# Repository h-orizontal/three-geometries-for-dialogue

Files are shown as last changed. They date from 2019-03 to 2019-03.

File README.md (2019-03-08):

# Three geometries for dialogue
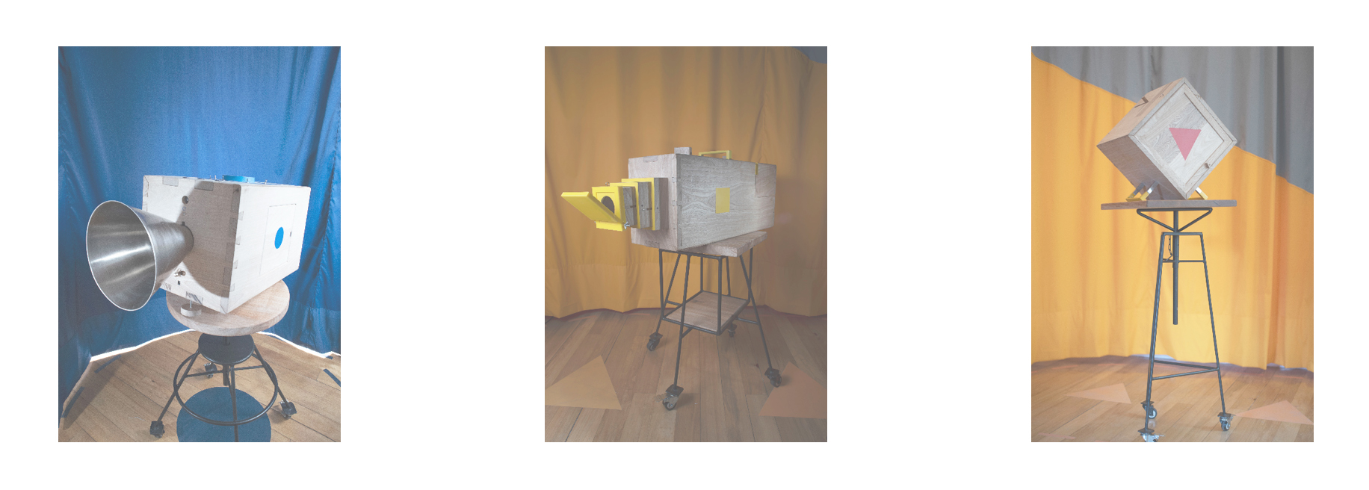
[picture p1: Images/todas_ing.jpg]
cajitas


These are three pedagogical tools that work as a support for psychosocial processes and exercises, as well as mediators in the participatory construction of a restorative justice space. These devices want to be translators of the life testimonies, feelings and circumstances that made the conflict or felony happen and transform them into communication exercises that bring facts closer and make them tangible, that foster dialogue and a mutual understanding of agreements and reparation.

Developed by [h-orizontal](http://h-orizontal.org/) alongside a group of collaborators, these devices are organized around three different communication systems: trace, sound and projection. Witch each box, [a series of workshops and a space intervention](http://h-orizontal.org/en/estrategia/restorative-justice-program-in-bogota/) were developed for the adolescents and professionals from the restorative justice program for adolescents in Bogotá, Colombia.

horizontal open sourced the design so that in the future they could be made by the adolescents themselves, other restorative justice initiatives or anyone interested in participative and interactive design processes.

To find out more, visit the [project website](http://h-orizontal.org/en/estrategia/pedagogic-tools-for-restorative-justice/).

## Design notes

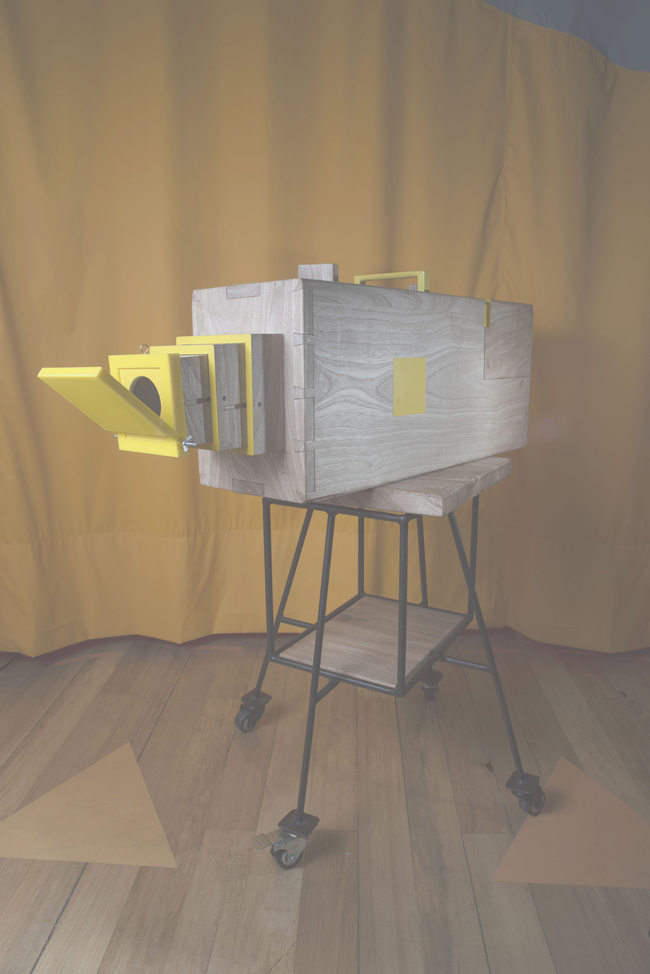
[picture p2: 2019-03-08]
Images/video.jpg

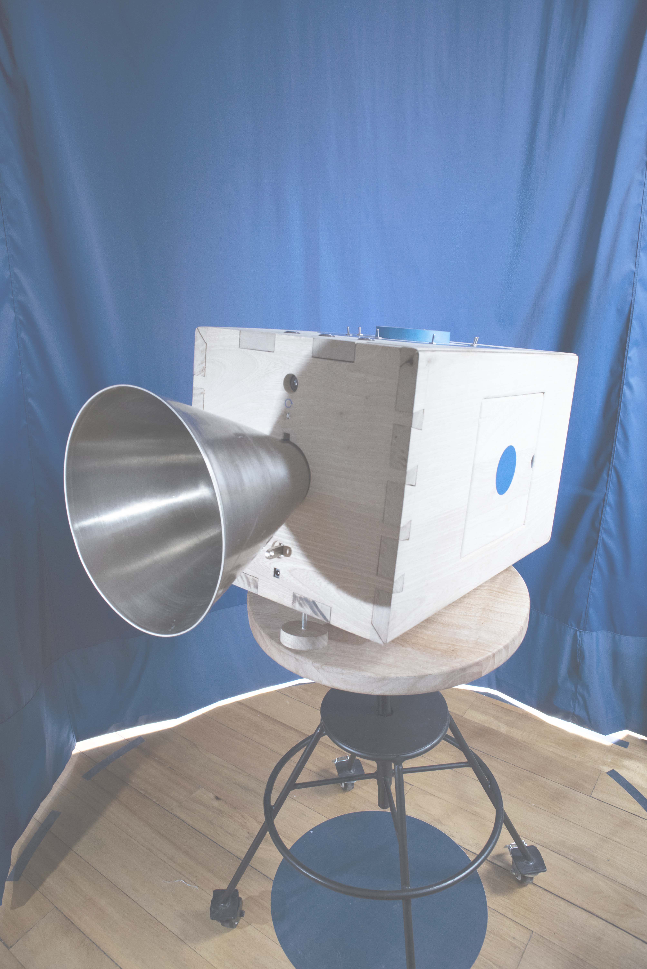
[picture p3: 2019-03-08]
Images/sonido.jpg

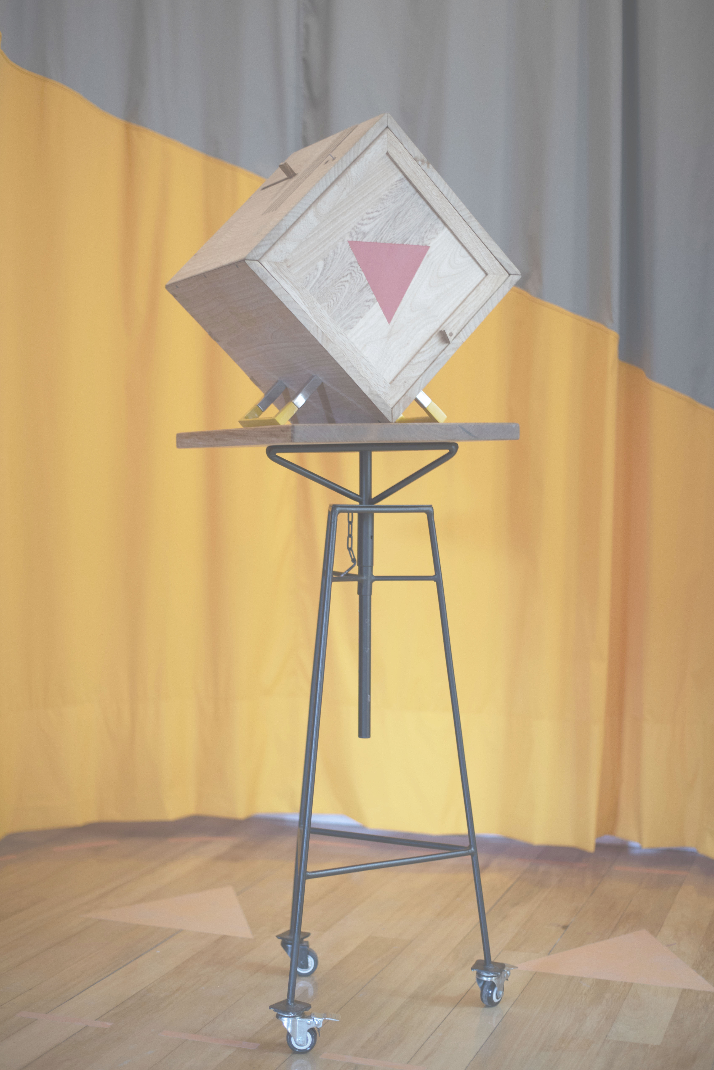
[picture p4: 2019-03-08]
Images/dibujo.jpg

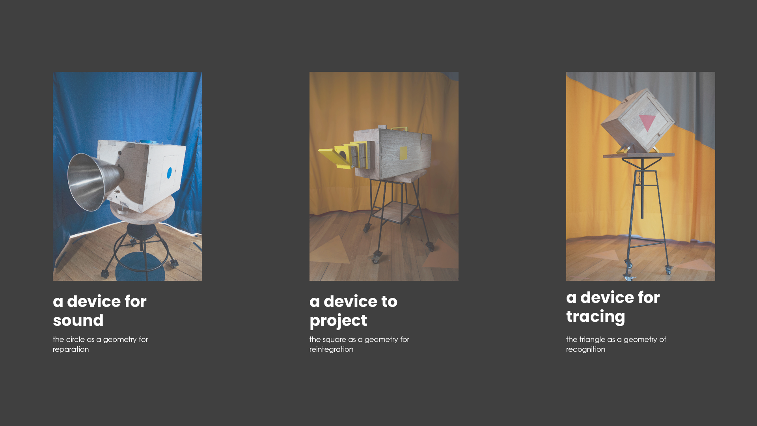
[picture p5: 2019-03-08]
Images/todas_ing.png

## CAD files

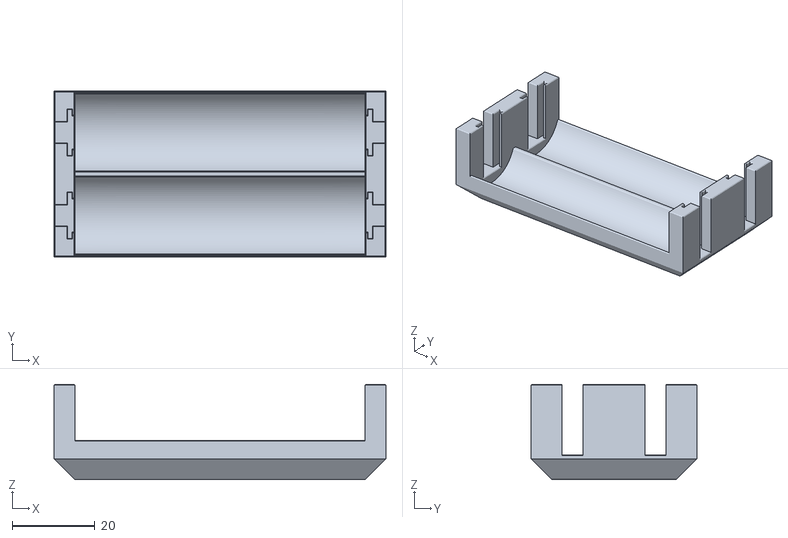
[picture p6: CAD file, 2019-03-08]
A Device for Tracing/A Device for Tracing [Battery Holder].stl
80.0 x 40.0 x 23.0

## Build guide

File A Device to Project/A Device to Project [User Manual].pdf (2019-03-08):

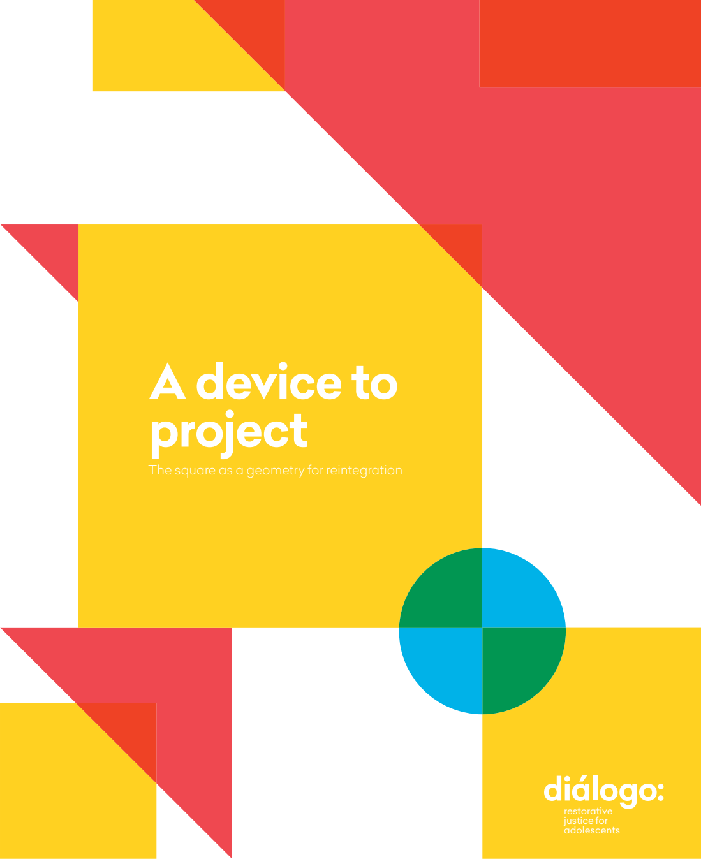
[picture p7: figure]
A device to project; restorative justice for adolescents; diálogo:

The square as a geometry for reintegration

# User manual

# The square as a geometry for reintegration

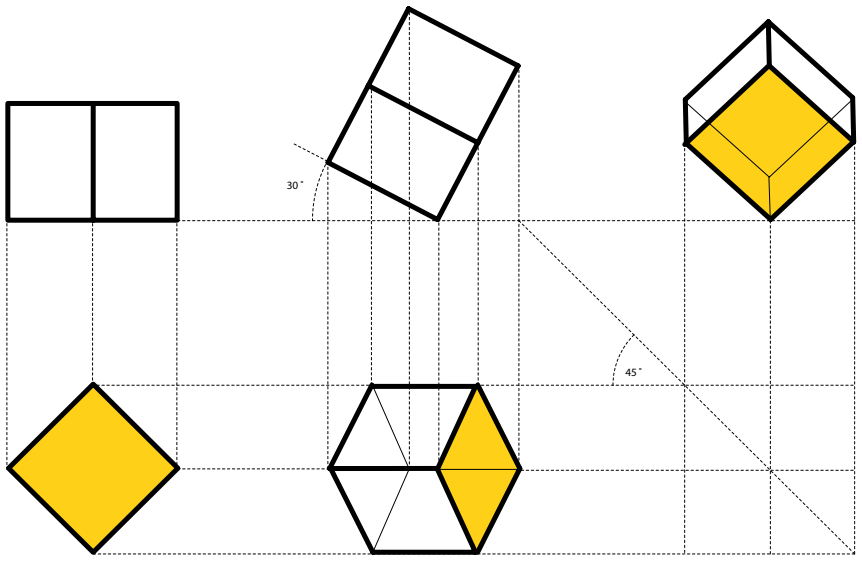
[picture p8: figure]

User manual

The square is the shape traditionally associated to space, an empty space that leads to endless possibilities of human activities. In some occasions, it is also seen as a frame that limits and contains space. To reintegrate is to project and, understanding that the square, as a limitless space, is in itself an exercise of self-projection that offers us the possibility of imagining who we want to
be and what we would do in different spaces: in my room, in my house, in my neighborhood, in my country… in the world.

What would happen if we could project the square on the space, thinking in the possibilities depending on the context and the moment?

What would happen if we could project ourselves on the square and imagine us in different scales and different spaces?

This is an artifact to project ourselves, imagine and establish new relationships.

User manual

# Contents

# 1. How is it assembled?

# 2. How is it used?

# 3. Pedagogical exercises to recognize

A device to project restorative justice for

adolescents

# 1. How is it assembled?

User manual

# Pieces

1. Structure
1A | 1 | Superior wooden door
1B | 1 | Lateral wooden door
1C | 1 | Inferior wooden door
1D | 1 | Lateral wooden door
1E | 1 | Internal wooden division
1F | 1 | Frontal wooden face
1G | 1 | Superior wooden drawer
1H | 1 | Inferior wooden drawer
1I | 1 | Superior wooden drawer’s cover
1J | 1 | Wooden storage box
1K | 12 | Wooden bump
2. Electronic components
2A | 1 | Interior sheet with magnifying glass
2B | 1 | Interior sheet
2C | 1 | Adjustable support for cellphone
2D | 1 | Wooden goggles
3. Exercises kit
3A | 4 | Post-its
3B | 10 | Pencils
3C | 2 | Instruction cards
3D | 1 | User manual

# Pieces

# 1. Structure

A device to project restorative justice for

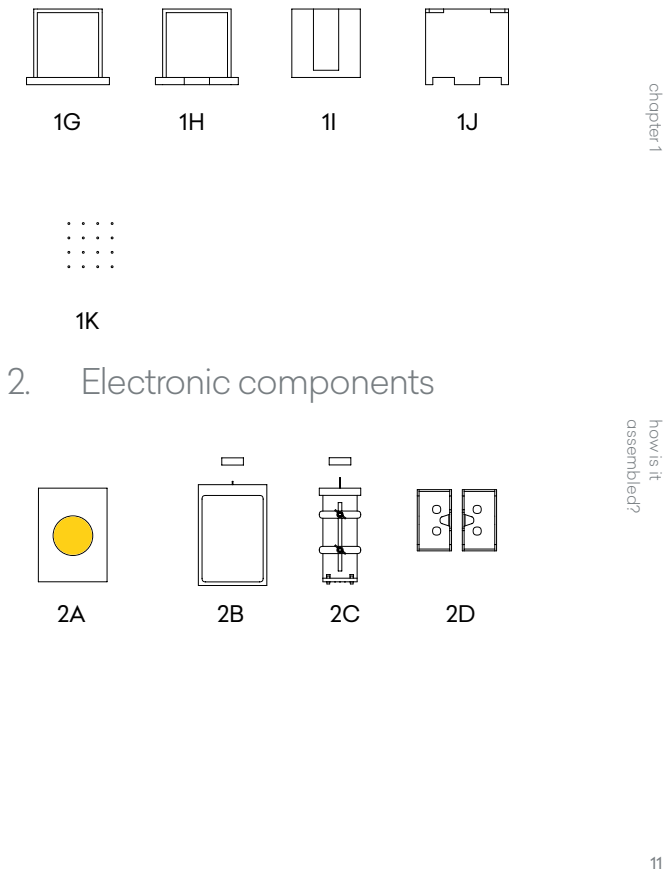
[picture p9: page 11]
assembled?; 2. Electronic components

how is it chapter 1

A device to project restorative justice for

adolescents

# 3. Exercises kit

3A | 3B

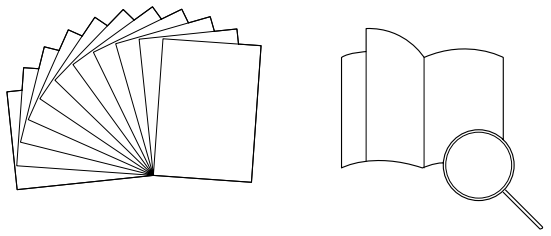
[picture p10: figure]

3C | 3D

# Mobile support

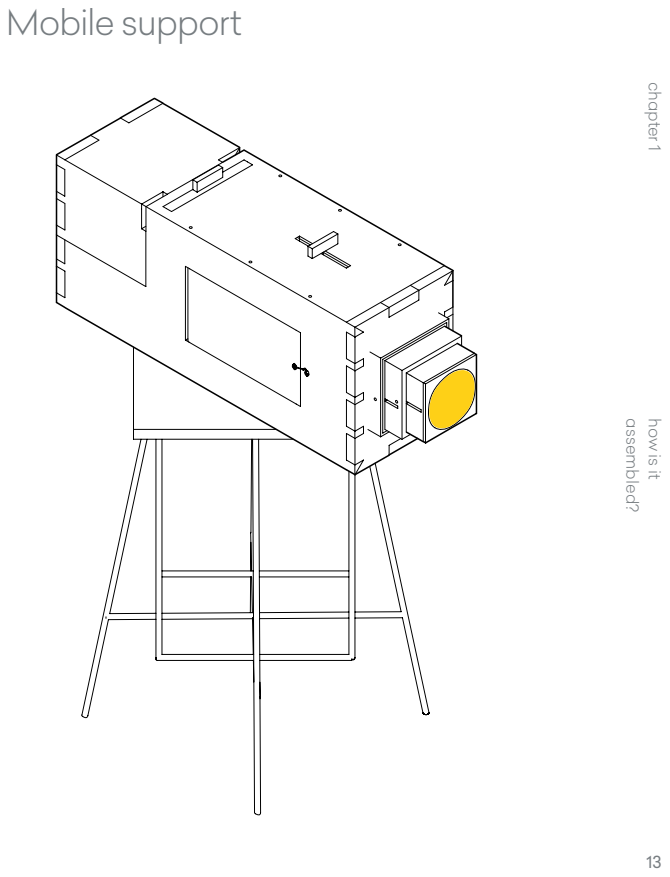
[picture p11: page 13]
assembled?

how is it chapter 1

A device to project restorative justice for

Support with aperture.

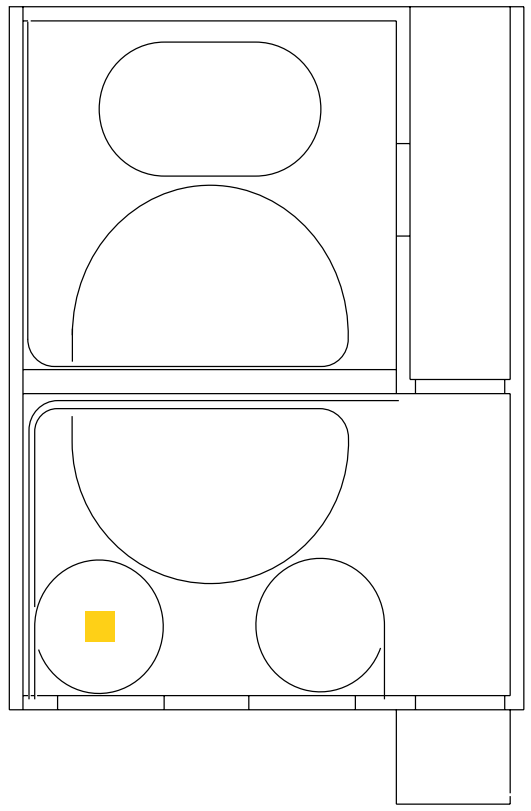
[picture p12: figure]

assembled?

how is it chapter 1

Location in the space.

# Assembly guide

1

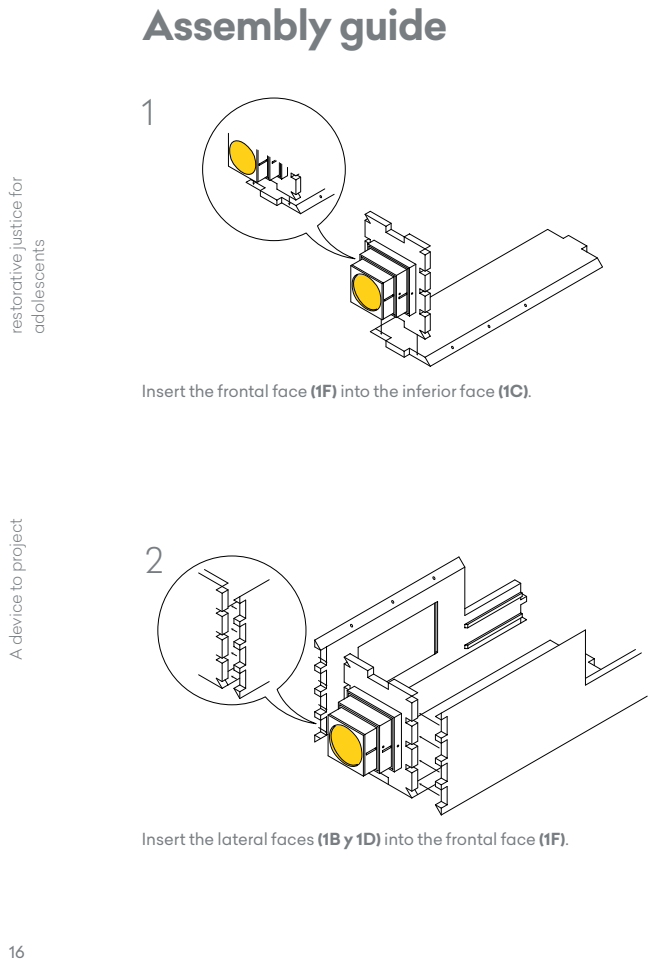
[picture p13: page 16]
adolescents

A device to project restorative justice for

Insert the frontal face (1F) into the inferior face (1C).

Insert the lateral faces (1B y 1D) into the frontal face (1F).

3

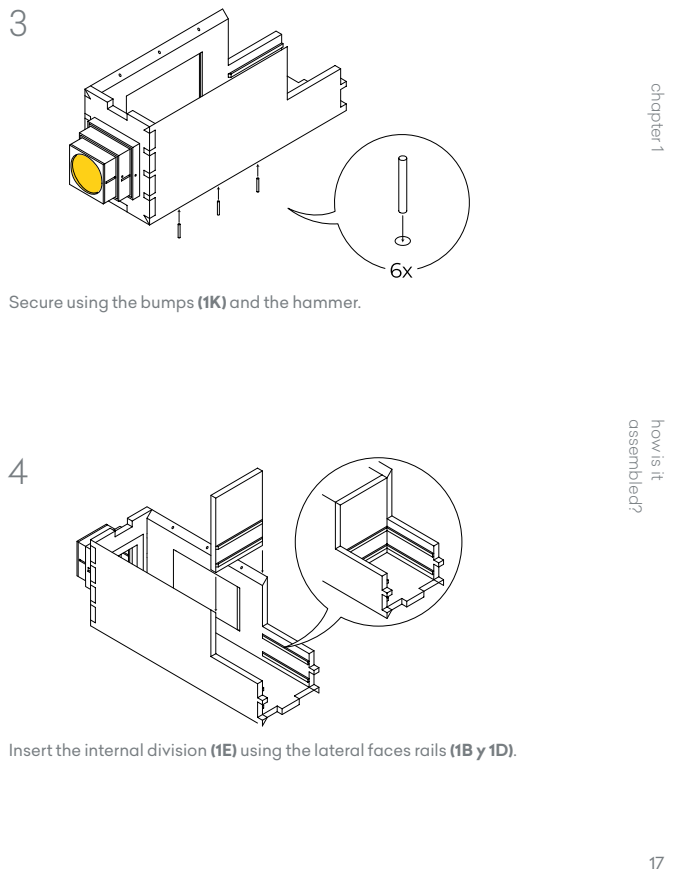
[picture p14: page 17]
assembled?

how is it chapter 1

Secure using the bumps (1K) and the hammer.

Insert the internal division (1E) using the lateral faces rails (1B y 1D).

5

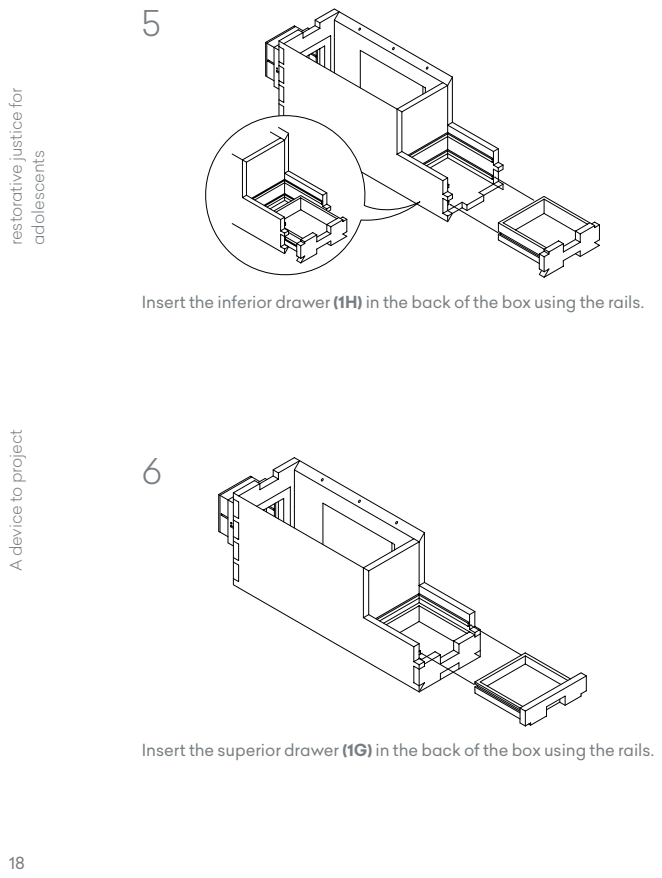
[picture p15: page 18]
adolescents

A device to project restorative justice for

Insert the inferior drawer (1H) in the back of the box using the rails.

Insert the superior drawer (1G) in the back of the box using the rails.

7

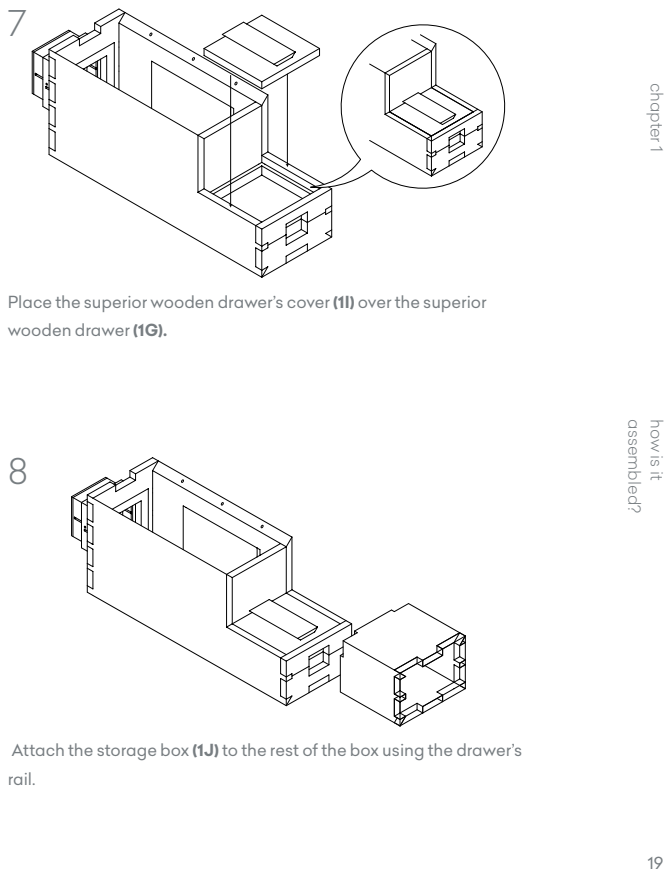
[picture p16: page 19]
assembled?

how is it chapter 1

Place the superior wooden drawer’s cover (1I) over the superior
wooden drawer (1G).

Attach the storage box (1J) to the rest of the box using the drawer’s
rail.

9

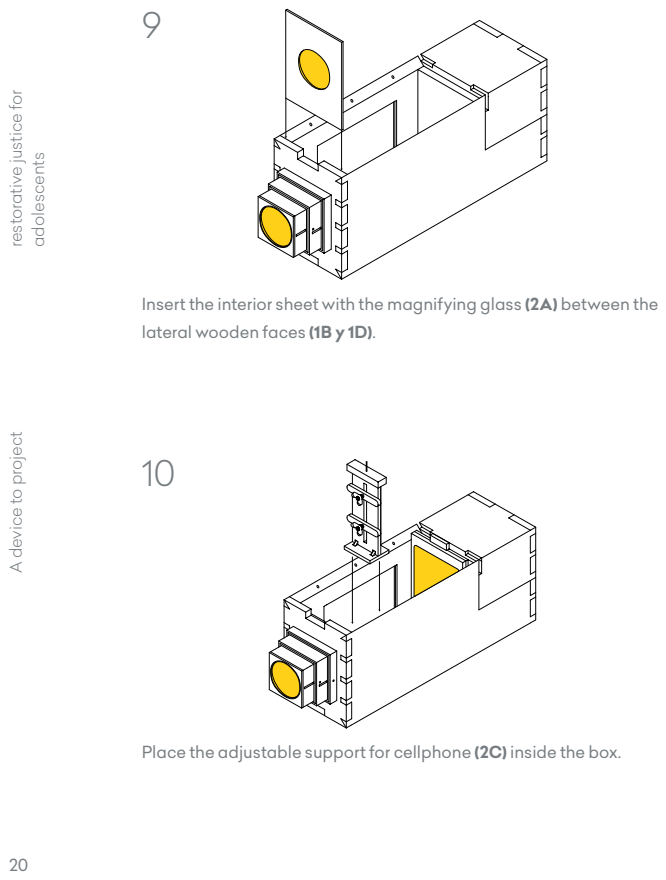
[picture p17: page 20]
adolescents

A device to project restorative justice for

Insert the interior sheet with the magnifying glass (2A) between the
lateral wooden faces (1B y 1D).

Place the adjustable support for cellphone (2C) inside the box.

11

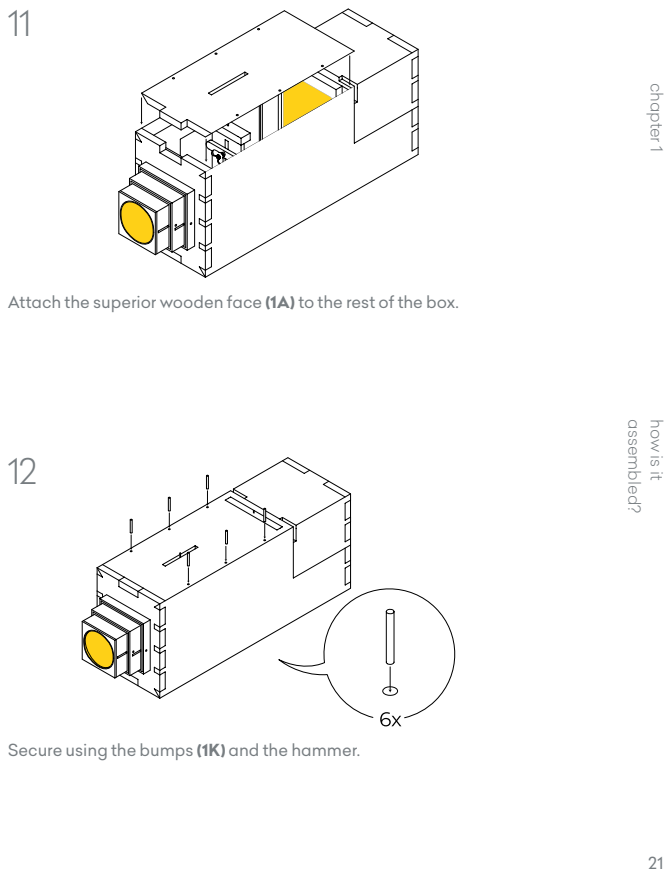
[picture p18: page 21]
assembled?

how is it chapter 1

Attach the superior wooden face (1A) to the rest of the box.

Secure using the bumps (1K) and the hammer.

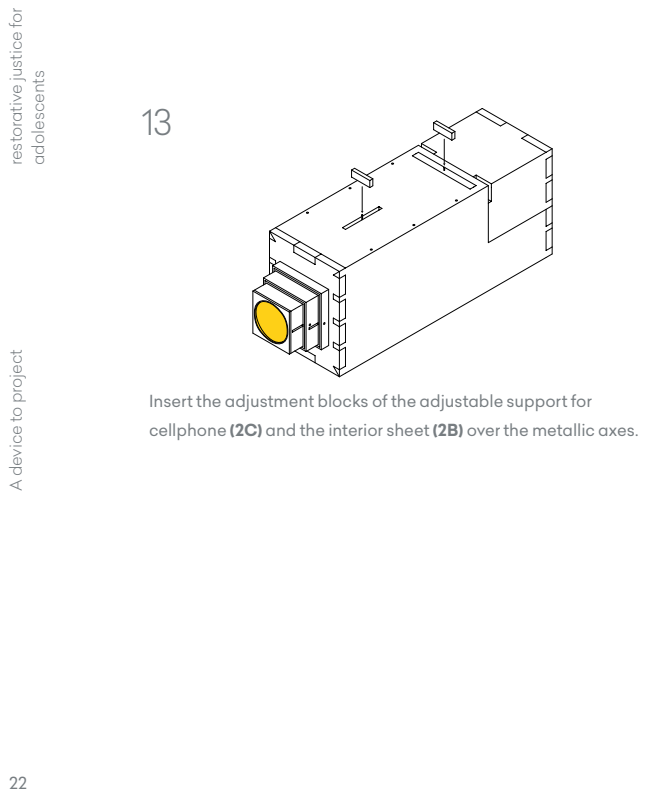
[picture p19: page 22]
adolescents

A device to project restorative justice for

Insert the adjustment blocks of the adjustable support for
cellphone (2C) and the interior sheet (2B) over the metallic axes.

11

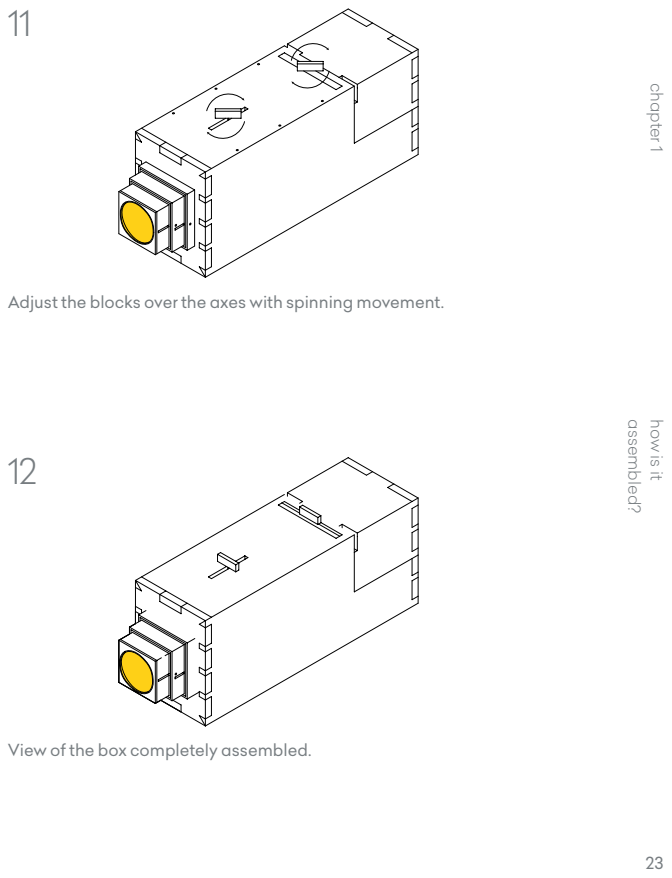
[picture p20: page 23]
assembled?

how is it chapter 1

Adjust the blocks over the axes with spinning movement.

View of the box completely assembled.

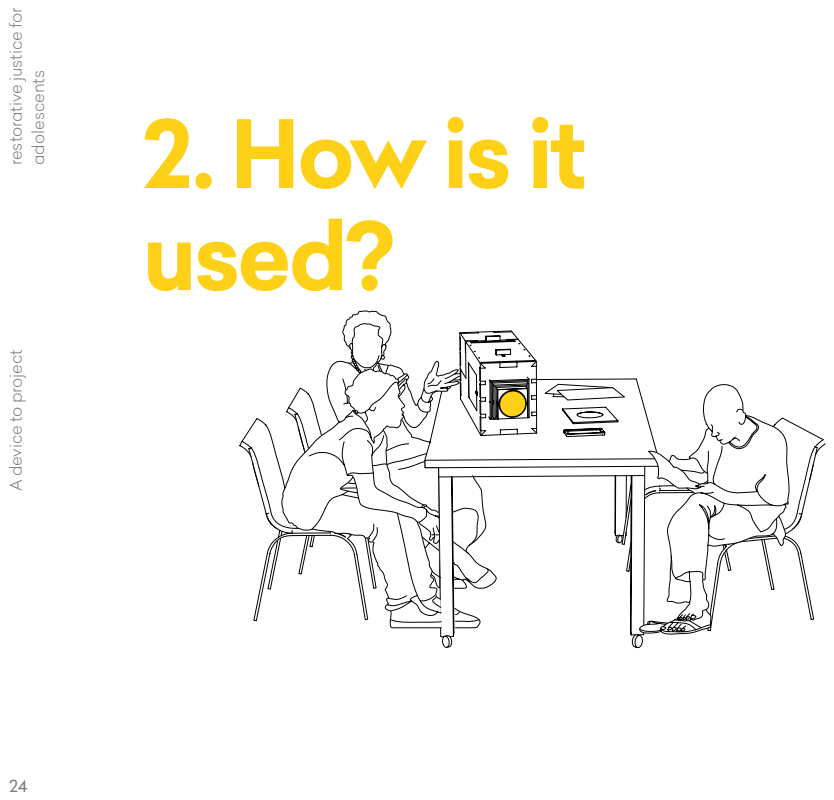
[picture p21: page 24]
adolescents

A device to project restorative justice for
2. How is it
used?

assembled?

how is it chapter 1

Once the image box is completely assembled and secured, it can be used in different ways.

It is possible to project images and videos from the inside of the box, horizontally or vertically, taking into account that an electronic device is needed with enough screen brightness that allows the magnifying glasses system to project and reproduce the device’s image outside the box.

Likewise, you can make use of the VR wood goggles that are inside the backside pocket, that allow you to see virtual reality images in 360º.

A device to project restorative justice for

Remove the superior face (1A) from the rest of the box .

Remove the adjustable support for devices (2C) from the inside of
the box.

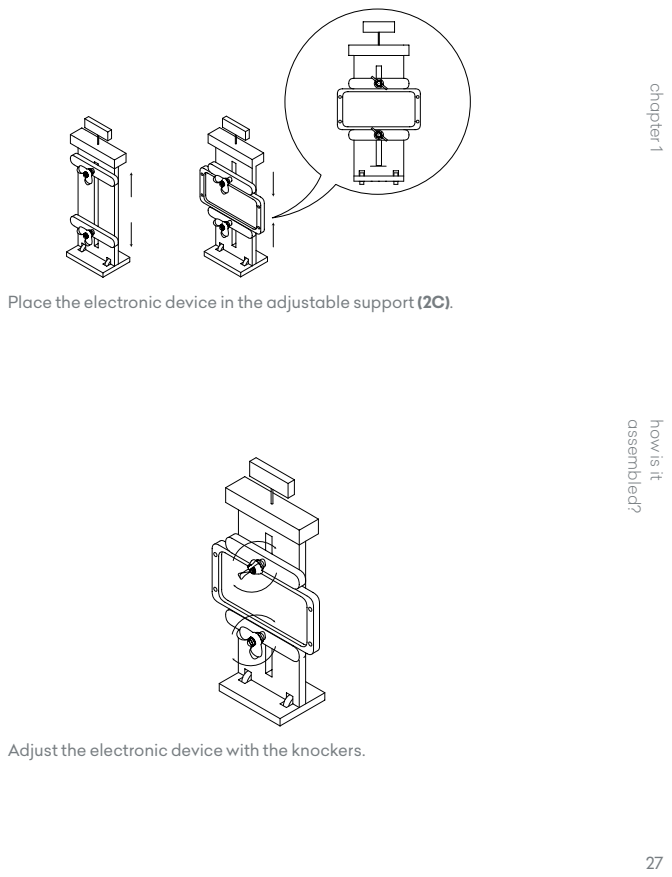
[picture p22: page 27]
assembled?

how is it chapter 1

Place the electronic device in the adjustable support (2C).

Adjust the electronic device with the knockers.

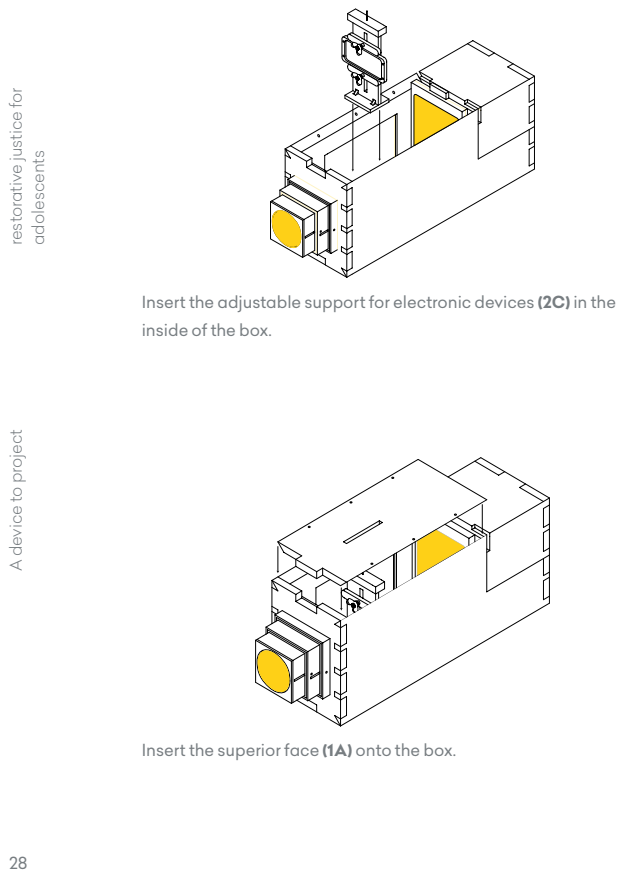
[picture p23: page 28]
adolescents

A device to project restorative justice for

Insert the adjustable support for electronic devices (2C) in the
inside of the box.

Insert the superior face (1A) onto the box.

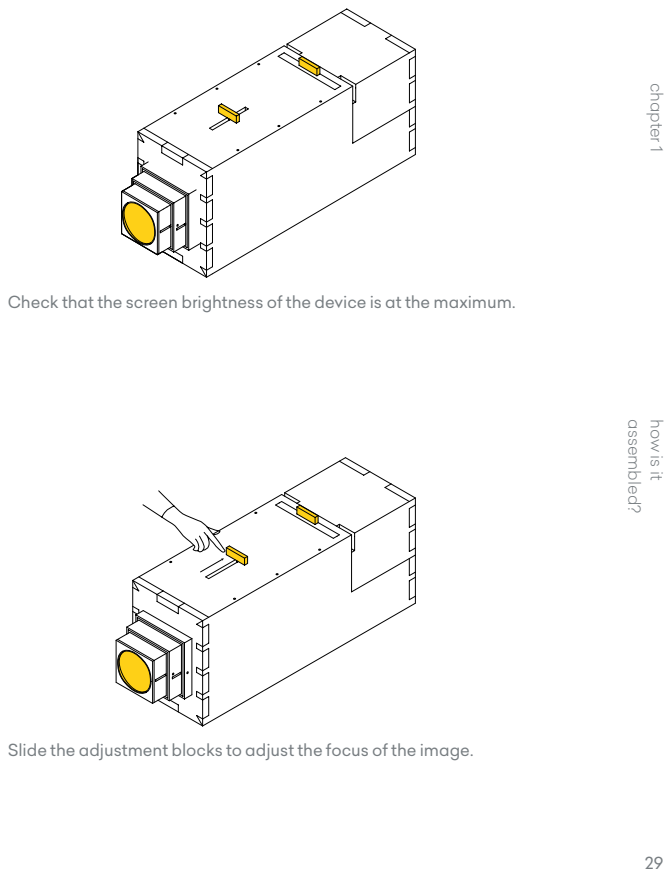
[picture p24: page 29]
assembled?

how is it chapter 1

Check that the screen brightness of the device is at the maximum.

Slide the adjustment blocks to adjust the focus of the image.

A device to project restorative justice for

To focus the image, remove the wooden bumps (1K) that hold the
lenses of the frontal face (1F).

Adjust the lenses until the projected image is clear.

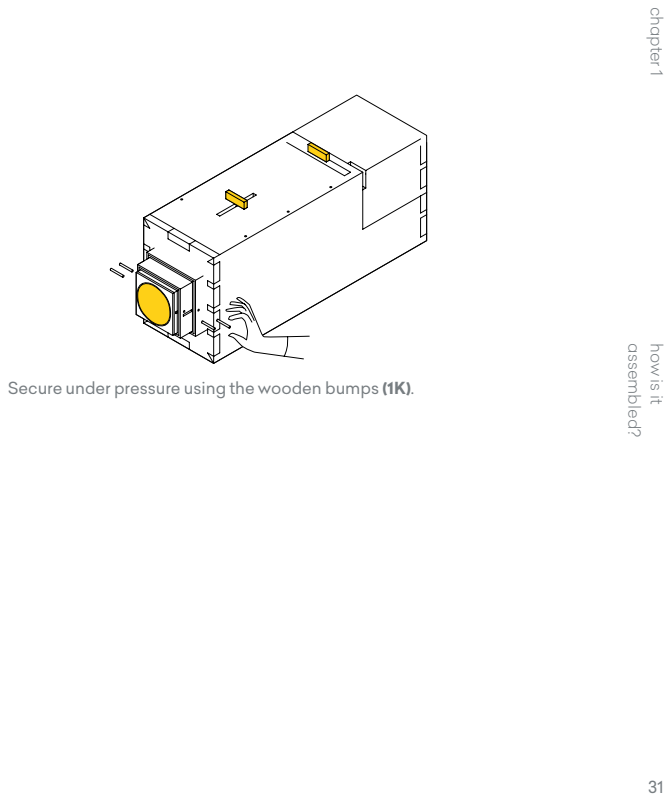
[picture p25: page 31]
assembled?

how is it chapter 1

Secure under pressure using the wooden bumps (1K).

A device to project restorative justice for

To visualize images in virtual reality, first remove the storage box
(1J) from the rest of the box.

Take out the VR goggles from the storage box.

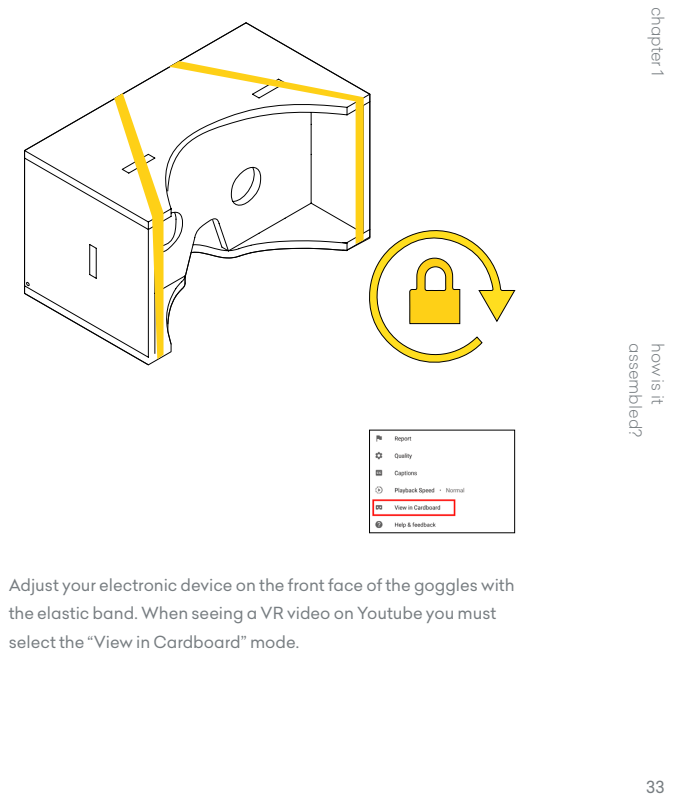
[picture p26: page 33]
assembled?

how is it chapter 1

Adjust your electronic device on the front face of the goggles with
the elastic band. When seeing a VR video on Youtube you must
select the “View in Cardboard” mode.

A device to project restorative justice for

adolescents

# IMPORTANT!

Once you are done using the Image box you should make sure that every piece is in its corresponding place; for example, the goggles must be inside the storage box, and the storage box must be set into the rail on the cover of the superior drawer. Likewise, the interior wooden sheet and the support for devices must be properly secured to avoid damaging the pieces.

Remember that with the help from this tool you will be able to visualize your projects and life plans; dare to project and chase them!

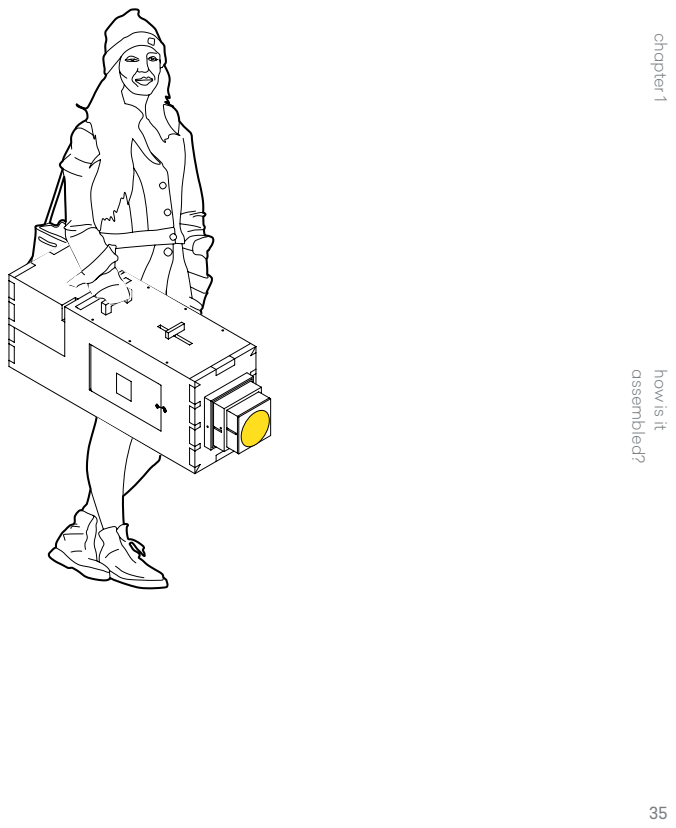
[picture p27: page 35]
assembled?

how is it chapter 1

A device to project restorative justice for

adolescents

# 3. Pedagogical exercises for recognition

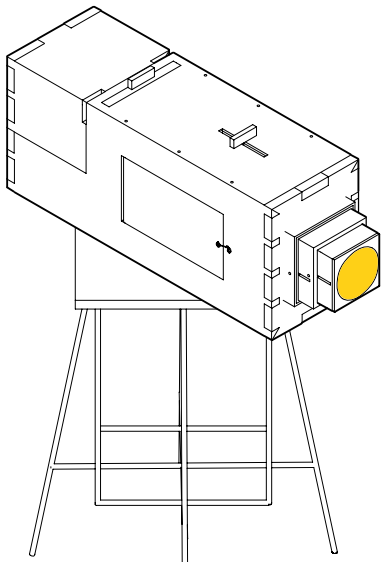
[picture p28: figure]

User manual

This device is a tool to complement the psychotherapeutic exercises that are part of the restorative justice program for adolescents. It aims to be an amplifier for possibilities within the restorative pedagogical processes.

Even though this object can be used in different ways and with countless exercises, we compiled a series of workshops, that have originated from the toolbox that the professionals from the program have been building together. This little exercise archive is arranged according to the potential that they have to generate individual or group reflection strategies, and hopes to add more exercises that come from the users experiences and of the different meanings that are given of this restorative process.

A device to project restorative justice for

adolescents

# The chain of life

# The victims and offender come in beside the facilitator. They will use their

cellphones and the projection box.

Let’s form a circle
We are all equal in this formation let’s take each others hands

Our right hand symbolizes
Our capacity to help
Our left hand symbolizes
Our need to receive

As we help
we must be helped
Nobody is so strong
to be always helping
Nobody is so weak
to be always helped

Let’s divide and reflect
Think of a moment where you helped Now think of one where you were helped

Record yourself narrating them

Now let’s watch everybody’s videos

recognition

pedagogical exercises for chapter 3

# The participants watch a video before the activity

The sensitization towards the activity must be carried out gradually.

Trough this exercise, the level of empathy of the people involved is measured. The offender’s communication style will be identified (assertive, passive or aggressive). Promoting personal development and relationships.
Respect for each other must prevail during the exercise.

At the end of the exercise, there is oral feedback with an emphasis on emotion recognition and the importance of human development within pacific coexistence.

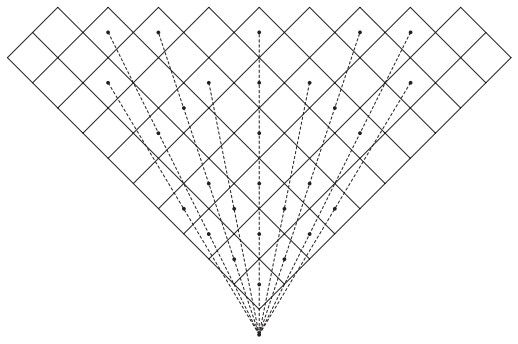
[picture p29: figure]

A device to project restorative justice for

adolescents

# Not judging is a part of understanding the other

# The victims and offender come in

beside their families and the facilitator.

# They will use their cellphones and the

projection box.

The facilitator must play videos
of different situations
of which the participants will express their perception

After this, each of the situations is explained
Showing how each moment
can be misunderstood

How would you act in each one of the situations?

Reflections are shared

recognition

pedagogical exercises for chapter 3

# The participants watch a video before the activity

The sensitization towards the activity must be carried out gradually.

To facilitate analysis of realities from the concept of moral development. Explaining how the individual perceives social reality through his existent internal structures.

At the end of the exercise, there is oral feedback with an emphasis on emotion recognition and the importance of human development within pacific coexistence.

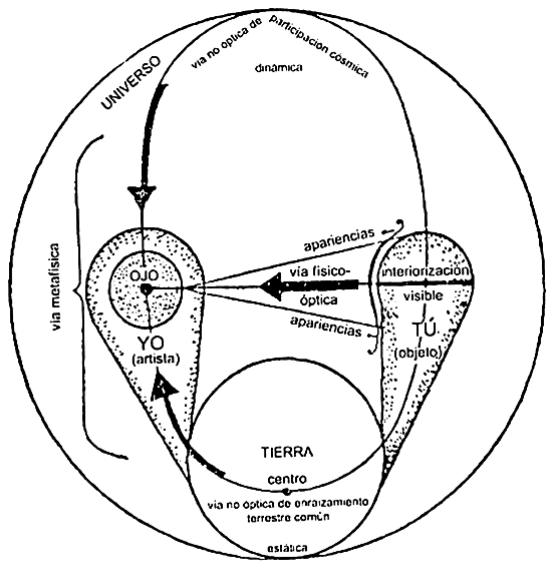
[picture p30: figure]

A device to project restorative justice for

adolescents

# Life karaoke

# The victims and offender come in beside the facilitator. They will use their

cellphones and the projection box.

Guiding the participants
through the prevention of drug use and pacific coexistence
The facilitator plays a series of songs

After this
Each one will choose a song
to interpret
in the form of karaoke

What were the impressions about the songs?

What values did you find in each song? Which is the first step to apply this value
in your daily life?

recognition

pedagogical exercises for chapter 3

# The sensitization towards the activity

must be carried out gradually.

Identifying attitudes that are associated with drug use prevention (indicated and selective). Generate discrepancy between the attitudes towards prevention vs the ones that tend to consume inside the adolescent penal system.

Facilitate the analysis of realities from the concept of moral development. Explain how the individual perceives social reality through his internal existent structures.

At the end of the exercise, there is oral feedback with an emphasis on emotion recognition and the importance of human development within pacific coexistence.

A device to project restorative justice for

recognition

pedagogical exercises for chapter 3

A device to project restorative justice for

adolescents

recognition

pedagogical exercises for chapter 3

A device to project restorative justice for

adolescents

recognition

pedagogical exercises for chapter 3

A device to project restorative justice for

adolescents

recognition

pedagogical exercises for chapter 3

A device to project restorative justice for

adolescents

recognition

pedagogical exercises for chapter 3

A device to project restorative justice for

adolescents

recognition

pedagogical exercises for chapter 3

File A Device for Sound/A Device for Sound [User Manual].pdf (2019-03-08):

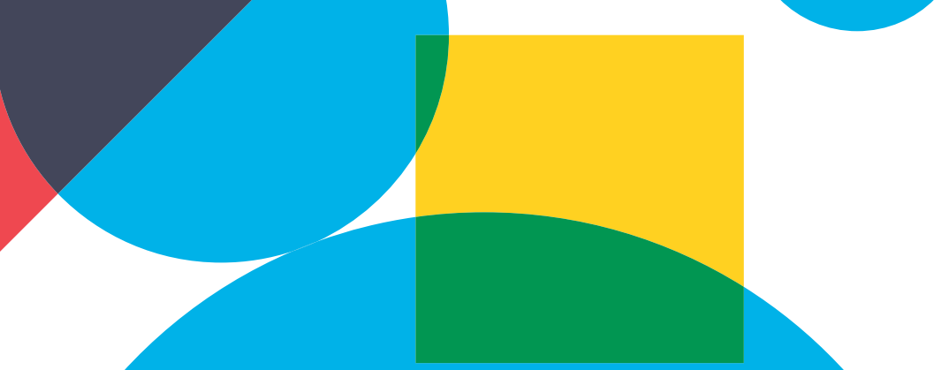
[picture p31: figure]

# A device for sound

The circle as a geometry for reparation

restorative
justice for
adolescents

# diálogo:

# User manual

# The circle as a geometry for reparation

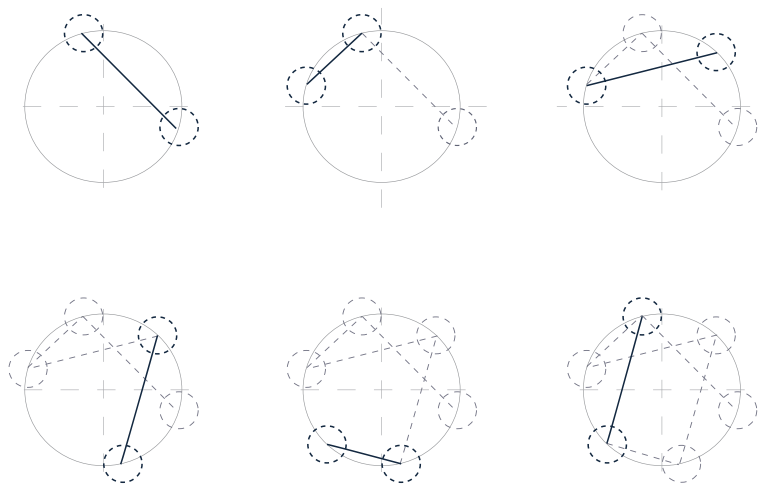
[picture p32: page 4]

User Manual

Circles are geometric shapes that provide a space for encounter in a way where hegemony given by a specific location doesn’t exist, but it is rather given by turns or specific moments. The circle makes it possible to focus attention on the person that is talking in one of the dialogue processes.

What would happen if every actor involved (the victim, the offender and the community) could have a recognizable voice within the restorative process?

What would happen if testimonies and words could be instruments for individual and collective reparation?

The artifact we present here gives value to words as a testimony and to the circle as a space for translation within a reparation process.

User Manual

# Contents

# 1. How is it assembled?

# 2. How is it used?

# 3. Pedagogical exercises for reparation

A device for sound restorative justice for

adolescents

# 1. How is it assembled?

User Manual

# Pieces

1. Structure
1A | 1 | Superior wooden face
1B | 1 | Inferior wooden face
1C | 1 | Frontal wooden face
1D | 2 | Lateral wooden faces
1E | 2 | Back doors
1F | 1 | Metallic cornet
1G | 1 | Speaker grill
1H | 16 | Wooden bump
1I | 4 | Acrylic interior separator
2. Electronic components
2A | 8 | Toggle switch
2B | 3 | Metallic button
2C | 7 | Blue LED
2D | 1 | White LED
2E | 1 | Blue light bulb
2F | 1 | Volume regulator
2G | 2 | Batteries
2H | 1 | Adapter
3.Exercise kit
3A | 10 | Colors
3B | 2 | Pencil sharpeners
3C | 2 | Eraser
3D | 1 | Hammer
3E | 10 | Instruction cards
3F | 1 | User manual

# Pieces

# 1. Structure

A device for sound restorative justice for

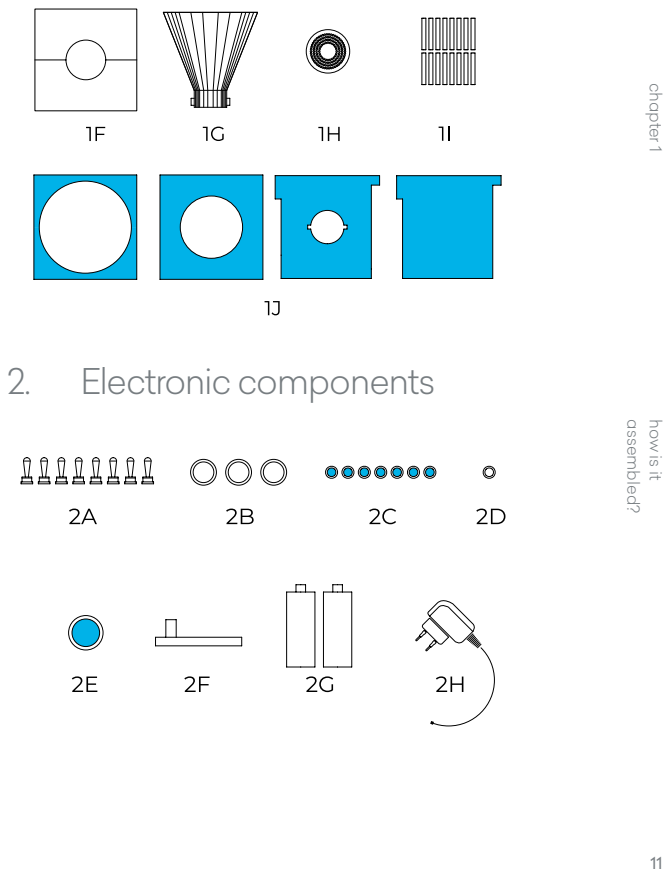
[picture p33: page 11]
assembled?; 2. Electronic components

how is it chapter 1

# 3. Exercise kit

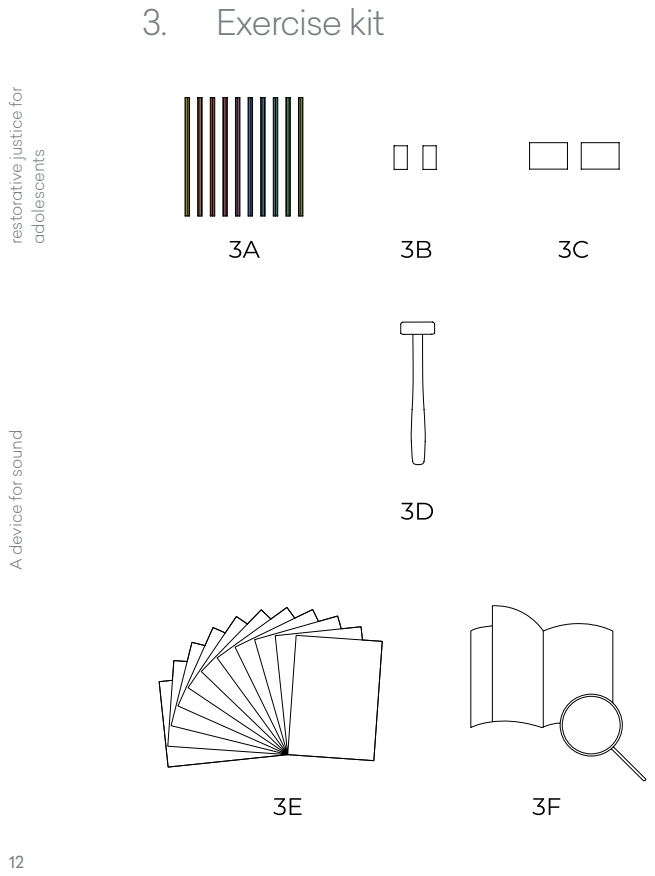
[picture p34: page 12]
adolescents

A device for sound restorative justice for

# Mobile support

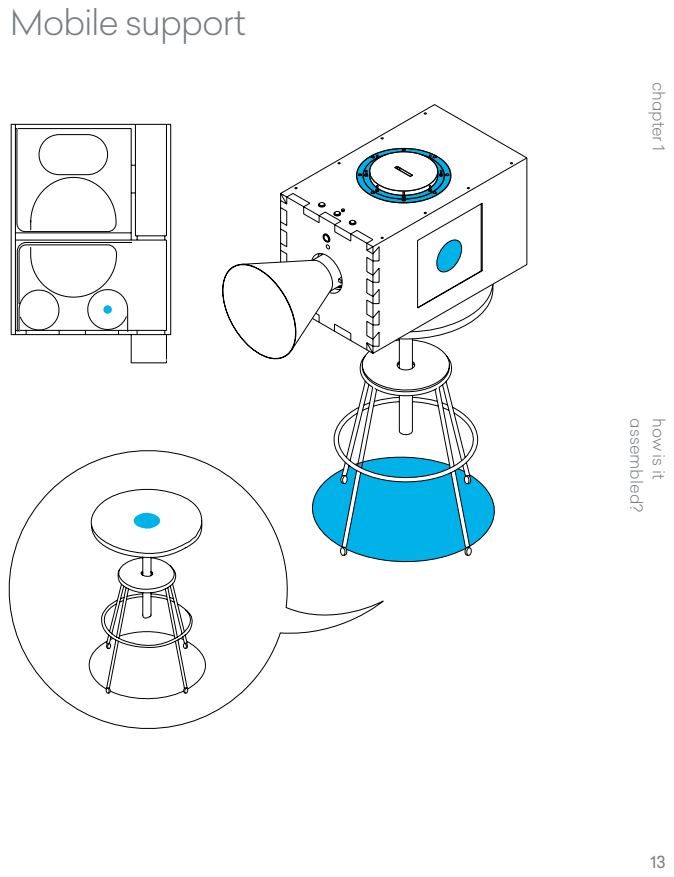
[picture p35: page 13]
assembled?

how is it chapter 1

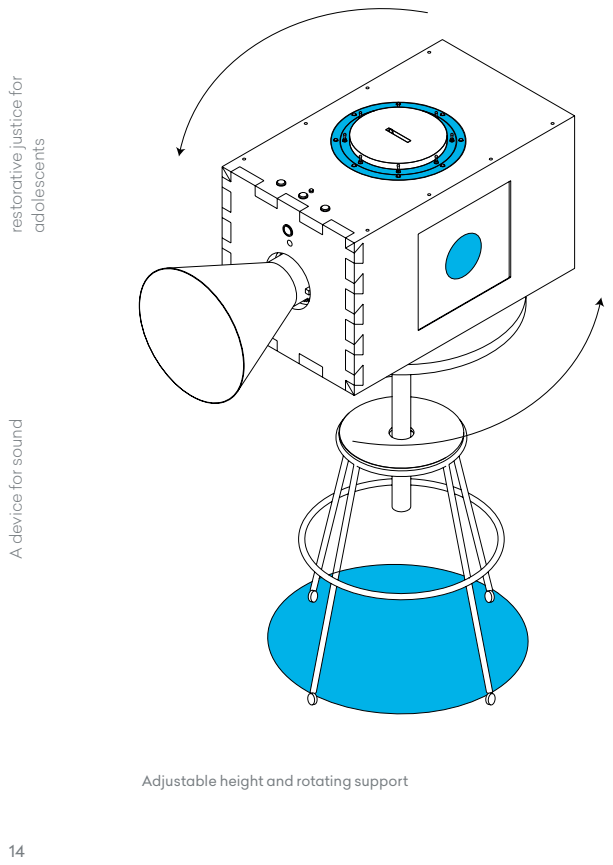
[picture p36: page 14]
adolescents

A device for sound restorative justice for

Adjustable height and rotating support

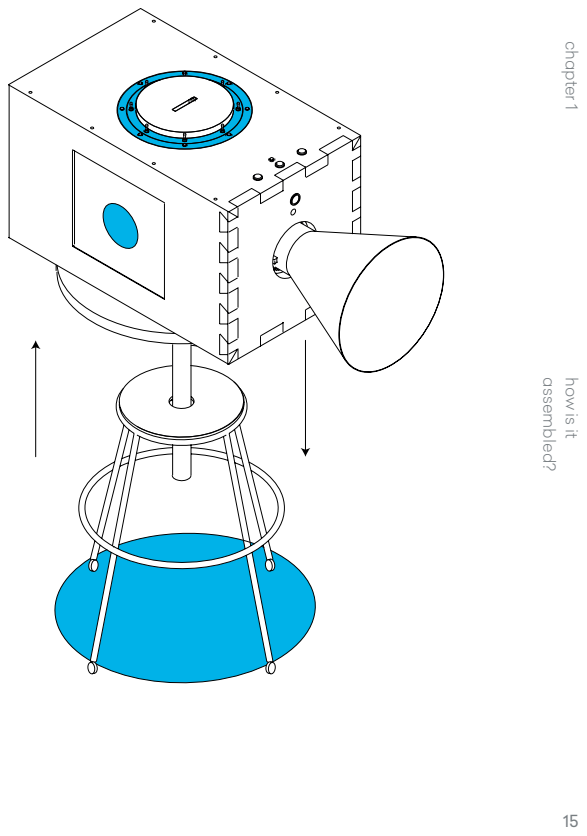
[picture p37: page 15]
assembled?

how is it chapter 1

# Assembly guide

1

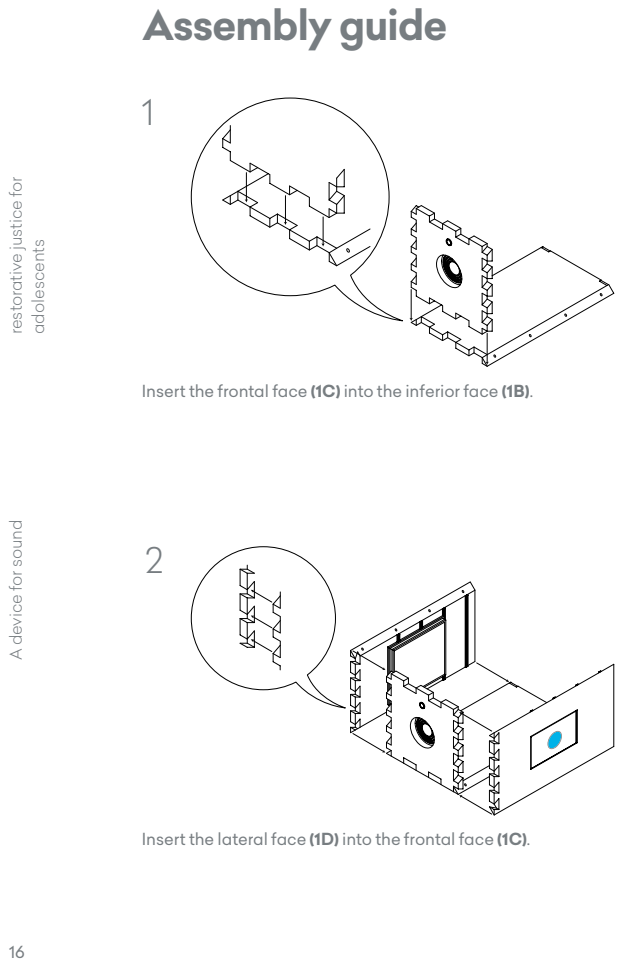
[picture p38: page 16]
adolescents

A device for sound restorative justice for

Insert the frontal face (1C) into the inferior face (1B).

Insert the lateral face (1D) into the frontal face (1C).

3

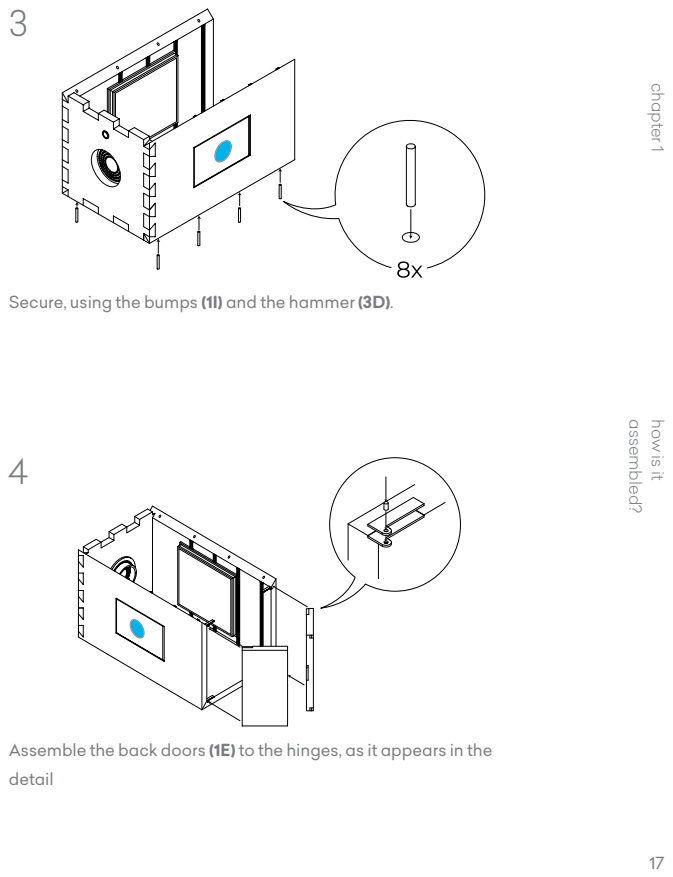
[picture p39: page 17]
assembled?

how is it chapter 1

Secure, using the bumps (1I) and the hammer (3D).

Assemble the back doors (1E) to the hinges, as it appears in the
detail

5

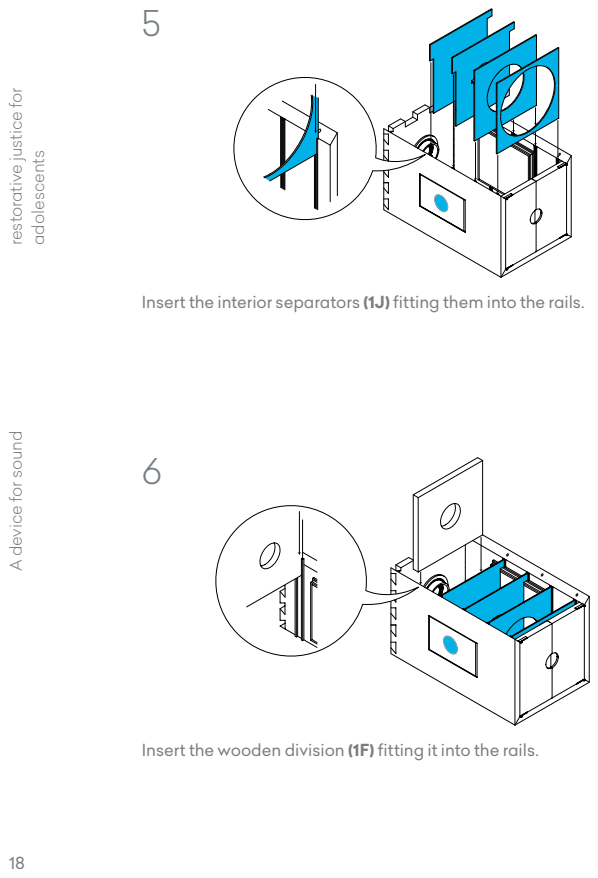
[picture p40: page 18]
adolescents

A device for sound restorative justice for

Insert the interior separators (1J) fitting them into the rails.

Insert the wooden division (1F) fitting it into the rails.

7

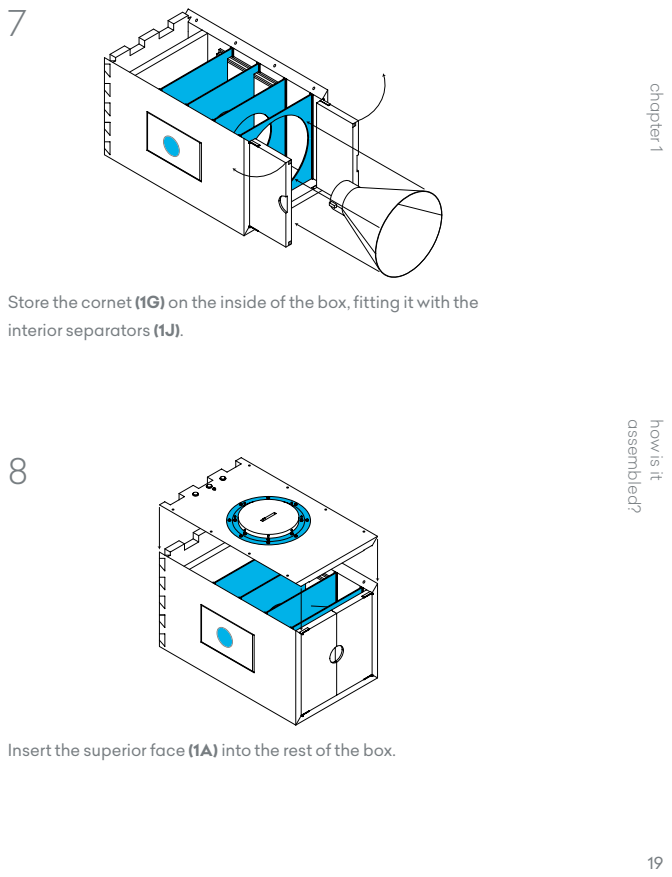
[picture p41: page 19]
assembled?

how is it chapter 1

Store the cornet (1G) on the inside of the box, fitting it with the
interior separators (1J).

Insert the superior face (1A) into the rest of the box.

9

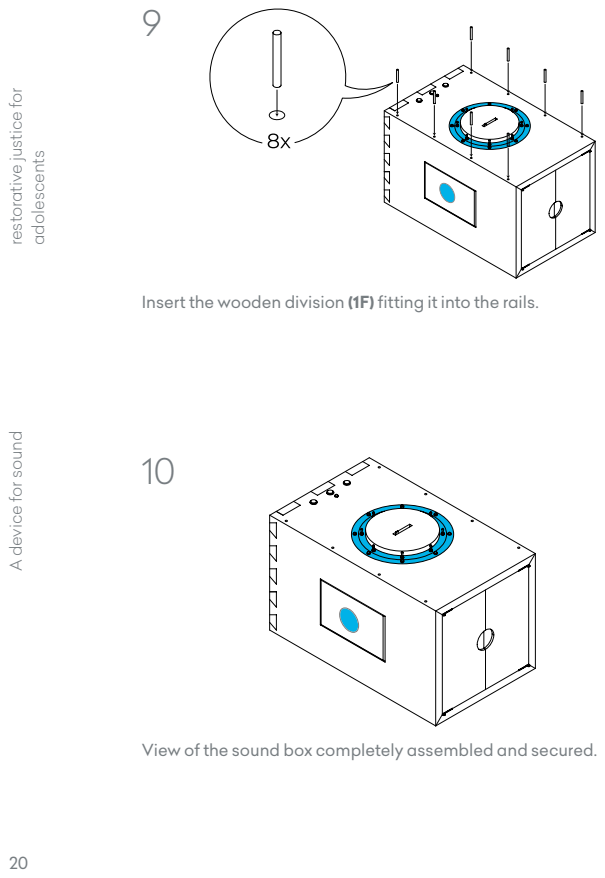
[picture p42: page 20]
adolescents

A device for sound restorative justice for

Insert the wooden division (1F) fitting it into the rails.

View of the sound box completely assembled and secured.

assembled?

how is it chapter 1

A device for sound restorative justice for

adolescents

# 2. How is it used?

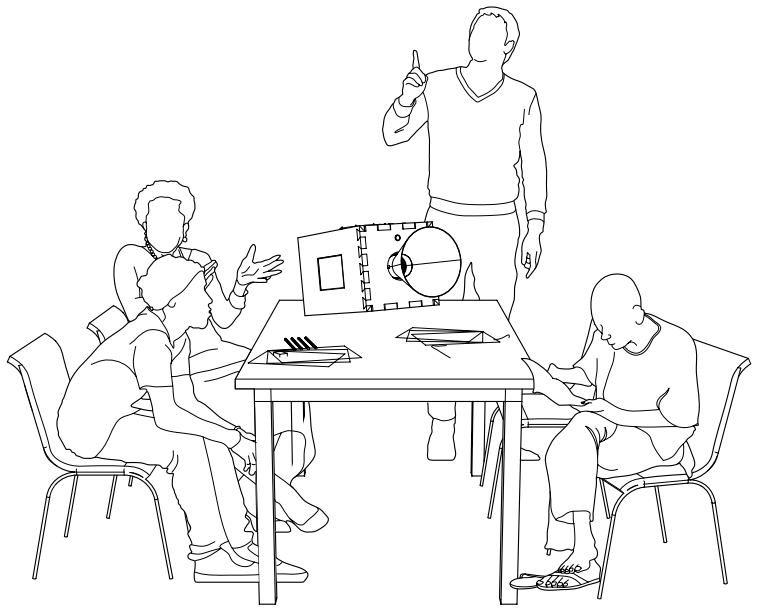
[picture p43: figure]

User Manual

Once the sound box has been completely assembled and secured, it can be used in different ways. From the control center located on the superior wooden face (1A), you will be able to record and reproduce audio, control the volume, stop and set the forward the audio. The metallic cornet that is stored inside the box, once it is installed on the outside of the box (1C), will help amplify sound and improve the audio’s quality.

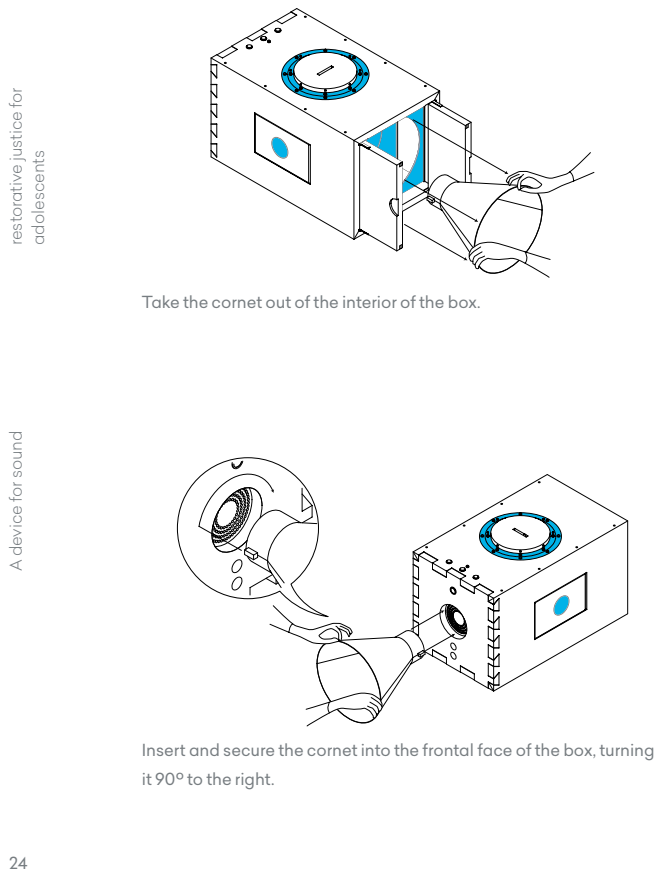
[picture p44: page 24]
adolescents

A device for sound restorative justice for

Take the cornet out of the interior of the box.

Insert and secure the cornet into the frontal face of the box, turning
it 90º to the right.

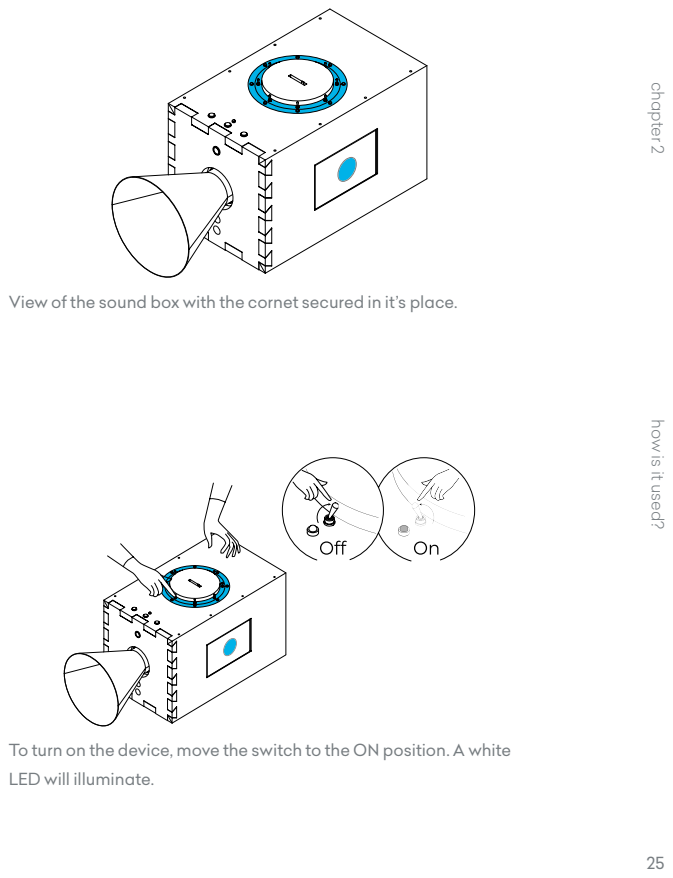
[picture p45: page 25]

25how is it used? chapter 2

View of the sound box with the cornet secured in it’s place.

To turn on the device, move the switch to the ON position. A white
LED will illuminate.

## Selection switch

A device for sound restorative justice for

ON Led light

ON/OFF switch

To raise and lower the volume move the slider from one end to the
other.

## Record

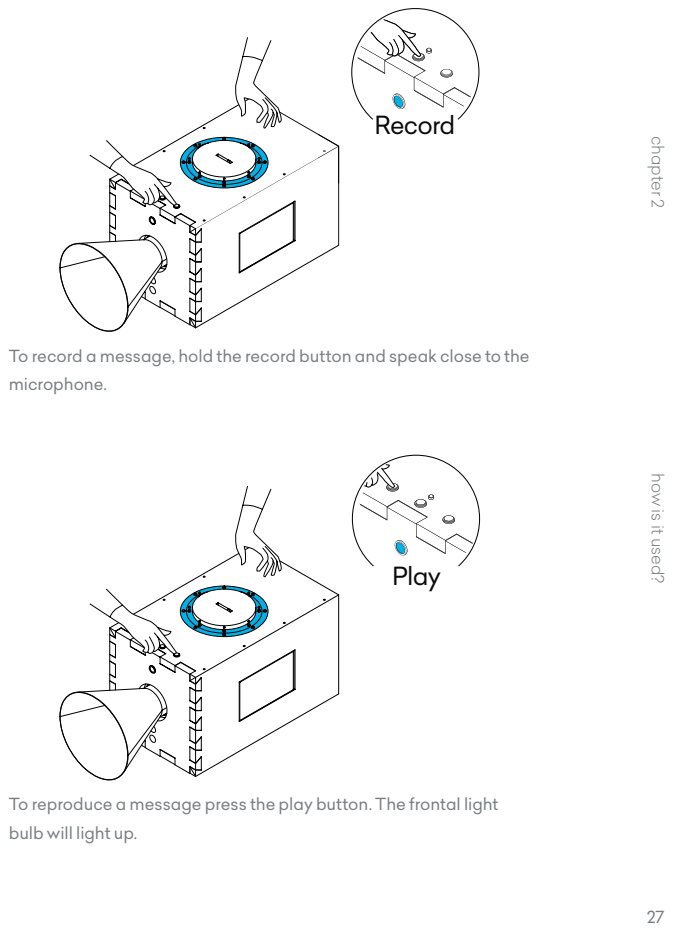
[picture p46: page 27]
Play

27how is it used? chapter 2

To record a message, hold the record button and speak close to the
microphone.

To reproduce a message press the play button. The frontal light
bulb will light up.

## Skip Play

adolescents; Play; Stop

A device for sound restorative justice for

To skip to the next audio press the forward button and then the play
button.

To listen to a recorded message turn on one of the switches. A blue
LED light will illuminate.


29how is it used? chapter 2

To play an audio from the USB, insert it in the USB port. It must have
7 tracks, that you will be able to reproduce turning on the button
that corresponds to each one, as it is shown in the diagram.

adolescents

A device for sound restorative justice for

The files that are stored in the memory card must be numbered
from 1 to 7. When you wish to change the files, the memory card
must be formatted to the exFAT file format.

Charge

31how is it used? chapter 2

To charge the device connect the adapter during 2 to 2 and a half
hours (complete battery charging estimated time).

A device for sound restorative justice for

adolescents

# IMPORTANT!

Once you are done using the sound box, don’t forget to disconnect the cables, shut down the system with the (OFF) switch and place each piece in its corresponding place; for example, the cornet must be kept inside the box, held between the acrylic separators, and the box must be completely closed. By using the box correctly and taking care of it, the sound box will be always at your service to be used again.


33how is it used? chapter 2

A device for sound restorative justice for

adolescents

# 3. Pedagogical exercises for recognition

User Manual


This device is a tool to complement the psychotherapeutic exercises that are part of the restorative justice program for adolescents. It aims to be an amplifier for possibilities within the restorative pedagogical processes.

Even though this object can be used in different ways and with countless exercises, we compiled a series of workshops, that have originated from the toolbox that the professionals from the program have been building together. This little exercise archive is arranged according to the potential that they have to generate individual or group reflection strategies, and hopes to add more exercises that come from the users experiences and of the different meanings that are given of this restorative process.

A device for sound restorative justice for

adolescents

# My Diary

# The victims come in beside the facilitator. There is a paper sheet with a list of negative adjectives over the table

along with papers and pens.

I am…
You, who are you?
Choose a quality from the paper sheet
from each of the lines
Write them on a paper
Now read them out loud while you record yourself with the box Saying “I am”
Now, let’s listen and reflect

In a conflict situation the basic attitudes are:
To compete, to please, to avoid or to collaborate

Think of 3 situations
in which you take one
of these attitudes

Read it out loud again
So that you can later listen to yourself with the box What do you think?

Personality is
static?
fluid?

recognition

pedagogical tools for chapter 3

# The participants write their thoughts on

a sheet of paper.

Have you noticed any problematic situation where you have thought “its winning or losing”, where what matters the most is achieving your goal? How did you feel?

Have you had any other situations where you have thought “I’d rather let him win”, where you don’t even think of your own objectives? How did you feel?

Or perhaps you lived other situations where “you both lose”? How did you feel?

Lastly, do you remember any situation where it was “win/win” for both? How do you feel?

A device for sound restorative justice for

recognition

pedagogical tools for chapter 3 punctual ambiguity
hurry up slowly
premeditated accident
defensive attack
eternal love
low altitude
grotesque beauty
controlled chaos
passive confrontation
science fiction
eternal present
finding yourself lost
silent scream
forgotten memories
sordid silence
daydreaming
tense calm
split union
OXYMORON

A device for sound restorative justice for

adolescents

# Restorative bird

# The victims come in beside the

facilitator. There are paper sheets, pens, scissors, markers, colors and pencils.

Do you know how to make and origami bird?
I will teach you
Let’s make one together

This winged beings
And send messages
With every unspoken word

But you must write them on their inside

With the letter
in which you wrote
your unspoken feelings
Make another bird

Words have weight
Paper makes them lighter

Now read the letter out loud
while you record with the box
using the function that deletes the message after it’s read

Listen to yourself

Let’s reflect

recognition

pedagogical tools for chapter 3

# The participants write their thoughts on

a sheet of paper.

A box is prepared (in plastic, cardboard, etc.) and is filled with cards that have different emotions written on them

The adolescents are instructed to write according to “interpret how you act and talk when you feel___________” (angry, happy, sad, surprised, scared, disgusted). This box must be placed in a visible place and be accessible to the participant.

At the end of the activity, the adolescent will express how he felt.

There is feedback from the exercise and the closure of the session/workshop is done (establishing compromises, agreements or homeworks if required).

A device for sound restorative justice for

adolescents

# Restorative bird

recognition; CENTR; NTRO; CENTER CENTER; CENTER; C E N T E R CENTER; CENT RE

pedagogical tools for chapter 3

A device for sound restorative justice for

adolescents

# The keyword

# The victims come in beside the facilitator. Cards with keywords about

the punishable act are on the table, along with paper sheets and pens.

Pick one of the cards randomly
Read it out loud
Immediately after describe
The meaning of that word for you

Do the same with each person If it is a group workshop

Let’s discuss
Does it really mean that?

From the discussion
Reflect
and write a new meaning

Now each one will read
the written meaning
while we record with the box

One after another will say:
Justice is…
Freedom is…

At the end we will listen to the recording of all the phrases

recognition

pedagogical tools for chapter 3

# The participants write their thoughts on

a sheet of paper.

Participants write their thoughts on a sheet of paper.

The keywords: Justice, Liberty, Responsibility, Damage, Truth, Offense, Reparation.

Complete the following sentences:
“You will be executed if…”
“Why live if…”
“You will be congratulated if you don’t say…” “I dream with one day being able to…”
“I want to rush to…”

A device for sound restorative justice for

adolescents


# CREATION

Increasingly less frequent crime.

# Eduardo Galeano

recognition

pedagogical tools for chapter 3

A device for sound restorative justice for

adolescents

recognition

pedagogical tools for chapter 3

A device for sound restorative justice for

adolescents

recognition

pedagogical tools for chapter 3

A device for sound restorative justice for

adolescents

recognition

pedagogical tools for chapter 3

A device for sound restorative justice for

adolescents

recognition

pedagogical tools for chapter 3

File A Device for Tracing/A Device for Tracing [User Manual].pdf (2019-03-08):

A device for tracing; restorative justice for adolescents; diálogo:

The triangle as a geometry of recognition

# User manual

# The triangle as a geometry of recognition

place; action; time; victims; ofender; community

User manual

The triangle is flat geometric shape with three sides. The common points in each pair of sides are called vertices. A triangle has three interior angles, three pairs of exterior congruent angles and three vertices among other elements. the triangle in restorative justice is used to schematize the presence of three actors, three primordial subjects in the process: victim – offender – community

What would happen if narrative turned into a tactic to recognize and to recognize ourselves?

What would happen if we traced phrases that could help us to recognize three variables (place-action-time) that really affect the three subjects involved in the restorative process?

This is an artifact to trace stories and recognize each other through responsibility.

User manual

# Contents

# 1. How is it assembled?

# 2. How is it used?

# 3. Pedagogical exercises to recognize

A device for tracing restorative justice for

adolescents

# 1. How is it assembled?

User manual

# Pieces

1. Structure
1A | 1 | Wooden door
1B | 1 | Inferior wooden face
1C | 1 | Frontal wooden face
1D | 1 | Superior wooden face
1E | 1 | Lateral wooden face
1F | 1 | Lateral wooden face
1G | 1 | Wooden sheet
1H | 1 | Acrylic container
1I | 12 | Wooden bump
1J | 5 | Projection acrylic
2. Electronic components
2A | 1 | Switch
2B | 1 | Power jack
2C | 2 | Batteries
2D | 1 | Circuit
2E | 1 | Adapter
3. Exercise kits
3A | 6 | Color markers
3B | 10 | Instruction cards
3C | 1 | User manual

# Pieces

# 1. Structure

adolescents

A device for tracing restorative justice for

assembled?; 2. Electronic components

how is it chapter 1

# 3. Exercise kit

adolescents

A device for tracing restorative justice for

# Mobile support

assembled?

how is it chapter 1

A device for tracing restorative justice for

adolescents

# Don’t forget to place the support over the triangle in the floor


Ubication in space.

assembled?

how is it chapter 1

Space signaling for the support.

# Assembly guide

1

adolescents

A device for tracing restorative justice for

Insert the frontal face (1C) into the inferior face (1B).

Insert the lateral face (1E) into the frontal face (1C).

3

assembled?

how is it chapter 1

Secure using the bumps (1I) and the hammer.

Insert the back door’s pivot (1A) into the lateral face hole (1E).

5

adolescents

A device for tracing restorative justice for

Insert the interior wooden sheet (1G) into the lateral face rail (1E).

Attach the lateral face (1F) to the rest of the box.

7

assembled?

how is it chapter 1

Secure using the bumps (1I) and the hammer.

Insert the acrylic containers (1H) into the lateral rails.

9

adolescents

A device for tracing restorative justice for

Attach the superior face (1D) to the rest of the box.

Secure using the bumps (1I) and the hammer.

11

assembled?

how is it chapter 1

Insert the projection acrylics (1J); each piece will fit in one of the
slits formed by the superior and lateral faces.

View of the tracing box completely assembled.

A device for tracing restorative justice for

adolescents

# 2. How is it used?

User manual

Once the tracing box has been assembled and secured it is ready to use. As you turn on the light with the toggle switch, the box will project the enlarged image that appears in the translucent acrylics, which you can intervene using the colored markers.

Likewise, by displacing the wood sheets placed in the interior, images can be adjusted.

adolescents

A device for tracing restorative justice for

With the box leaning on the handles, open the back door (1A).

Take out the projection acrylics (1J) and the color markers (3A).


25how is it used? chapter 2

Draw over the acrylics and inside the circles.

The drawing must be upside down, so when the box is projecting,
the drawing will be the right way up.

adolescents

A device for tracing restorative justice for

Insert the projection acrylics (1J); each piece will fit in one of the
slits formed by the lateral and frontal faces.

View of the tracing box completely assembled with the projection
acrylics.


27how is it used? chapter 2

To turn on the light, move the switch to the ON position.

The image will be projected on the surface.

adolescents

A device for tracing restorative justice for

To focus the image, displace the wooden sheet (1G) using the
lateral faces rails.


29how is it used? chapter 2

To charge the device connect the adapter during 2 or 2 and a half
hours (complete battery charging estimated time).

A device for tracing restorative justice for

adolescents

# ¡IMPORTANT!

Every time you finish using the Tracing Box, don’t forget to turn off the system using the switch and to place every piece in the right place. For example, the projection acrylics must be placed in the interior of the box and the box must be completely closed. Don’t forget to charge the box using the adapter to use it again.


31how is it used? chapter 2

A device for tracing restorative justice for

adolescents

# 3. Pedagogical exercises for recognition

User manual


This device is a tool to complement the psychotherapeutic exercises that are part of the restorative justice program for adolescents. It aims to be an amplifier for possibilities within the restorative pedagogical processes.

Even though this object can be used in different ways and with countless exercises, we compiled a series of workshops, that have originated from the toolbox that the professionals from the program have been building together. This little exercise archive is arranged according to the potential that they have to generate individual or group reflection strategies, and hopes to add more exercises that come from the users experiences and of the different meanings that are given of this restorative process.

A device for tracing restorative justice for

adolescents

# My lifestyle

# Victims or offenders come in with the facilitator. Over the table there are paper

sheets and pens.

Let’s gather in circle
write on a piece of paper
the activities you do
everyday

Mark with X
non-healthy activities
Mark with O
healthy activities

Analyze the activities
Which one of them affects your body Which one of them affects your family Which one of them affects the community

Draw each of these
on the three circles
of the tracing box triangles

Share with the group
the reasons
of each drawing

Actions don’t affect only you they grow like a tree
until they reach every grade

recognition

pedagogical exercises for chapter 3

# Participants write their thoughts on the

sheet of paper.

Would you believe me if I tell you that every sheet of paper has the ability to turn in the tree of which it was made?

Cut the paper by half, beginning from the superior margin and almost to the center of the sheet. This way we have a trunk and two big branches. Fold every branch outwards with an angle of 30°.

Now cut every branch by half the same way you did with the first cut but with some more distance from the edge of the previous cut. Continue cutting the branches by half and fold them.

The sheet of paper is now a tree.

A device for tracing restorative justice for

adolescents

# “A tree is the slow explosion of a seed”

recognition

pedagogical exercises for chapter 3

A device for tracing restorative justice for

adolescents

# Functional analysis of the conduct

# Victims come in with the facilitator. Over

the table there are paper sheets, pens, scissors, color markers and pencils.

Let’s identify a problem
Which are the emotional,
cognitive, physiological and motor answers?

Try to draw the symbol of each one
in the circles of the triangle

Let’s identify on a sheet of paper
the background and the consequences

Stimulus-answer-stimulus

Which are the variables from the organism? which from the environment?
How do they impact in the problem?

Let’s formulate a hypothesis about the
problem

What would be the topography of the problem?

Form-duration-intensity

Let’s reflect

recognition

pedagogical exercises for chapter 3

# Participants write their thoughts on the

sheet of paper.

To identify the problematic behavior alongside the offender, specifying what he does, feels and thinks about it.

To define alongside the offender the circumstances of the context associated to that problematic behavior.

To establish alongside the offender the circumstances (what do the others do?, what benefits or losses reports the person? how do you feel after?) of the problematic behavior.

To recognize the dispositional variables relatively stable in the person or the context that could precipitate in the problematic behavior or could influence in the person to a greater vulnerability to emit the problematic behavior, by this we mean the background.

A device for tracing restorative justice for

adolescents

recognition

pedagogical exercises for chapter 3

A device for tracing restorative justice for

adolescents

recognition

pedagogical exercises for chapter 3

A device for tracing restorative justice for

adolescents

recognition

pedagogical exercises for chapter 3

A device for tracing restorative justice for

adolescents

recognition

pedagogical exercises for chapter 3

A device for tracing restorative justice for

adolescents

recognition

pedagogical exercises for chapter 3

A device for tracing restorative justice for

adolescents

recognition

pedagogical exercises for chapter 3

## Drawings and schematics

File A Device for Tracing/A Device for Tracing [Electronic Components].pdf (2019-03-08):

# A device for tracing

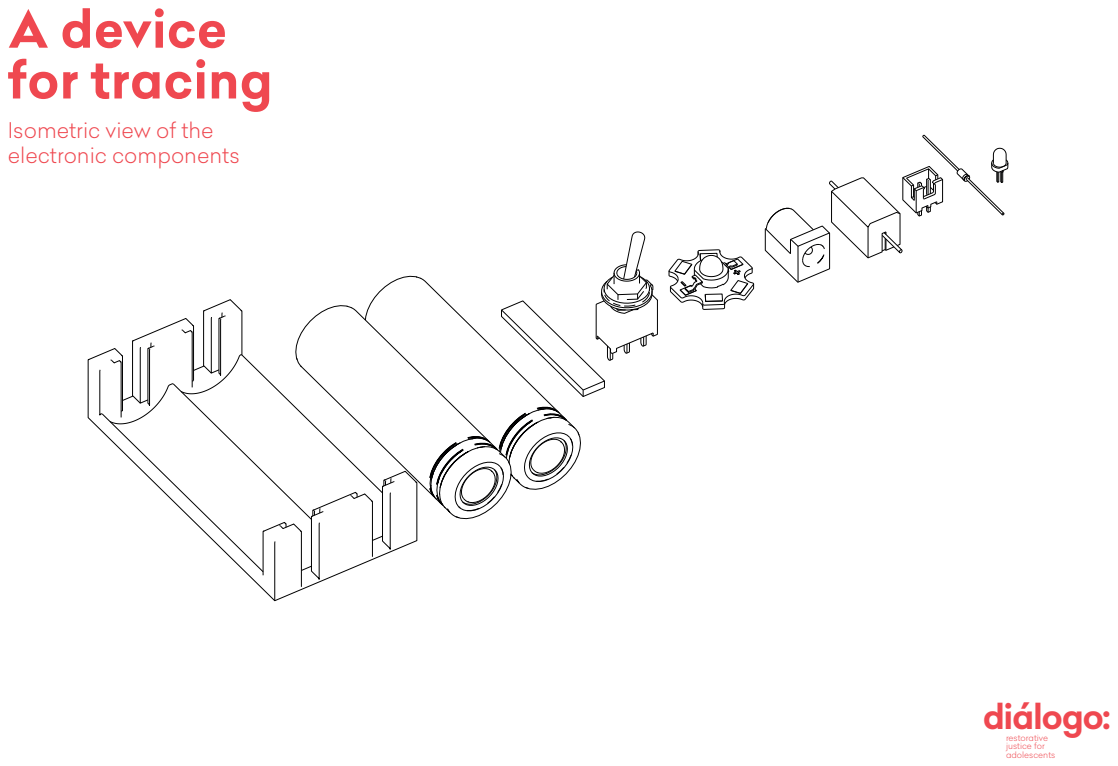
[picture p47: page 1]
diálogo: restorative; justice for adolescents

Isometric view of the
electronic components

# A device for tracing

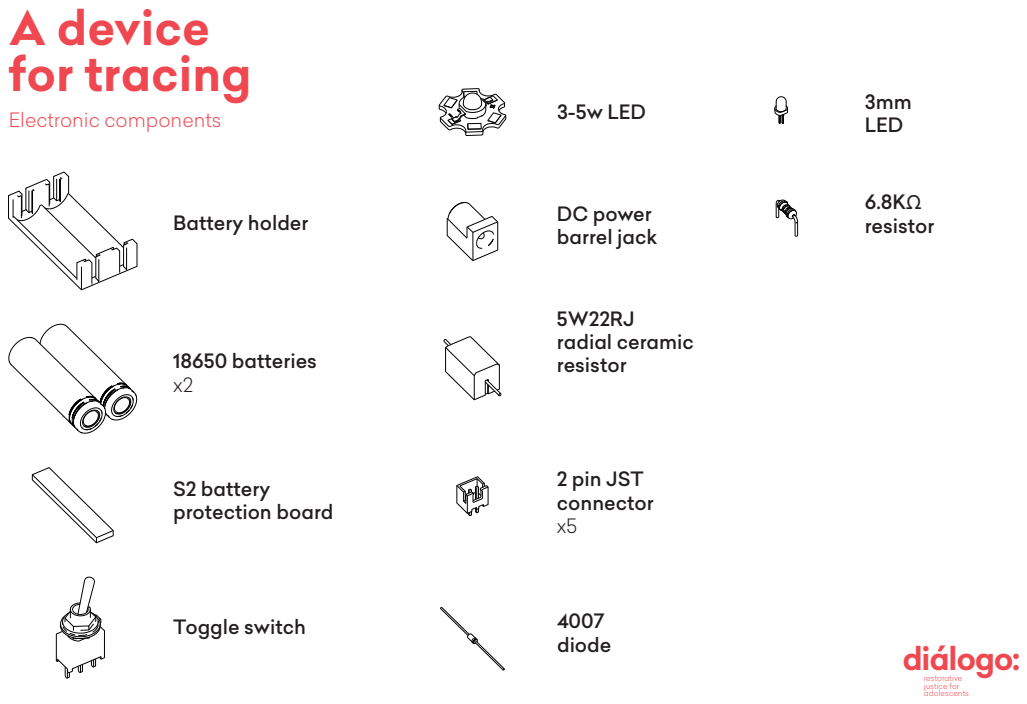
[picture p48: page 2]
Battery holder; Toggle switch; 3-5w LED; DC power barrel jack; 3mm LED; 6.8KΩ resistor; 5W22RJ radial ceramic resistor; 2 pin JST connector x5; 4007 diode; 18650 batteries x2; S2 battery protection board; diálogo: restorative; justice for adolescents; Electronic components

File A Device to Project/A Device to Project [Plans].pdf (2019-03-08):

# Isometric view of the pieces

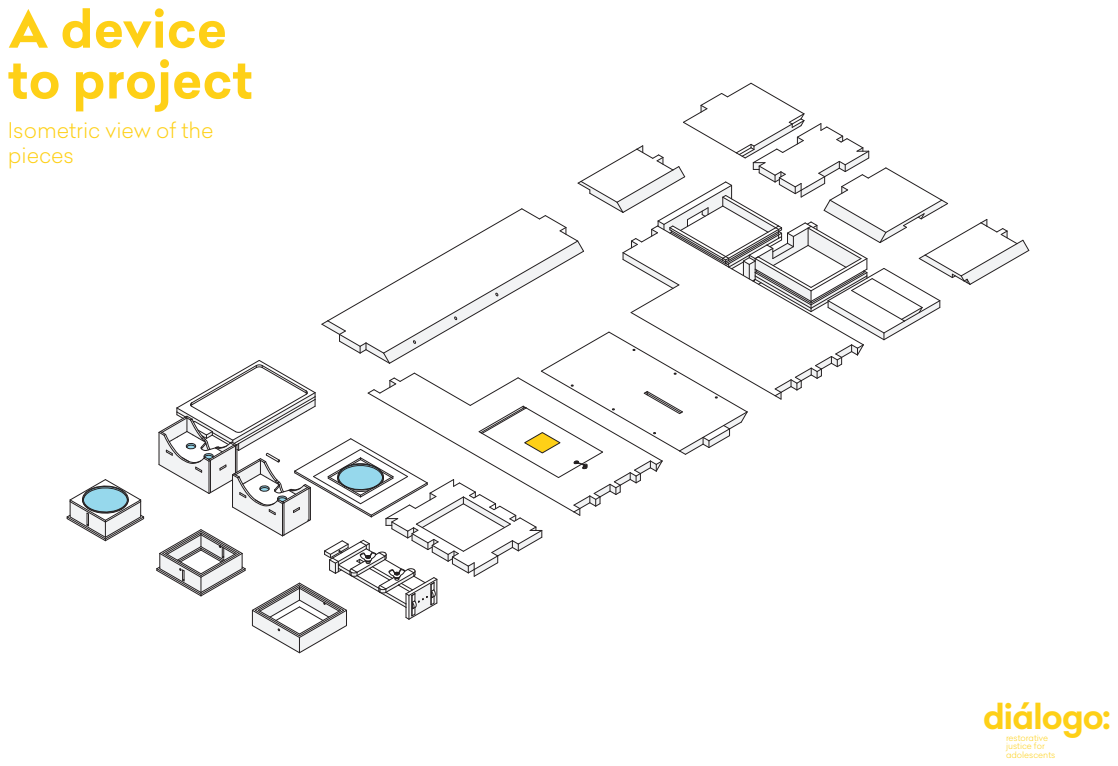
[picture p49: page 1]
restorative justice for adolescents; A device to project; diálogo:

# Pieces

# A device

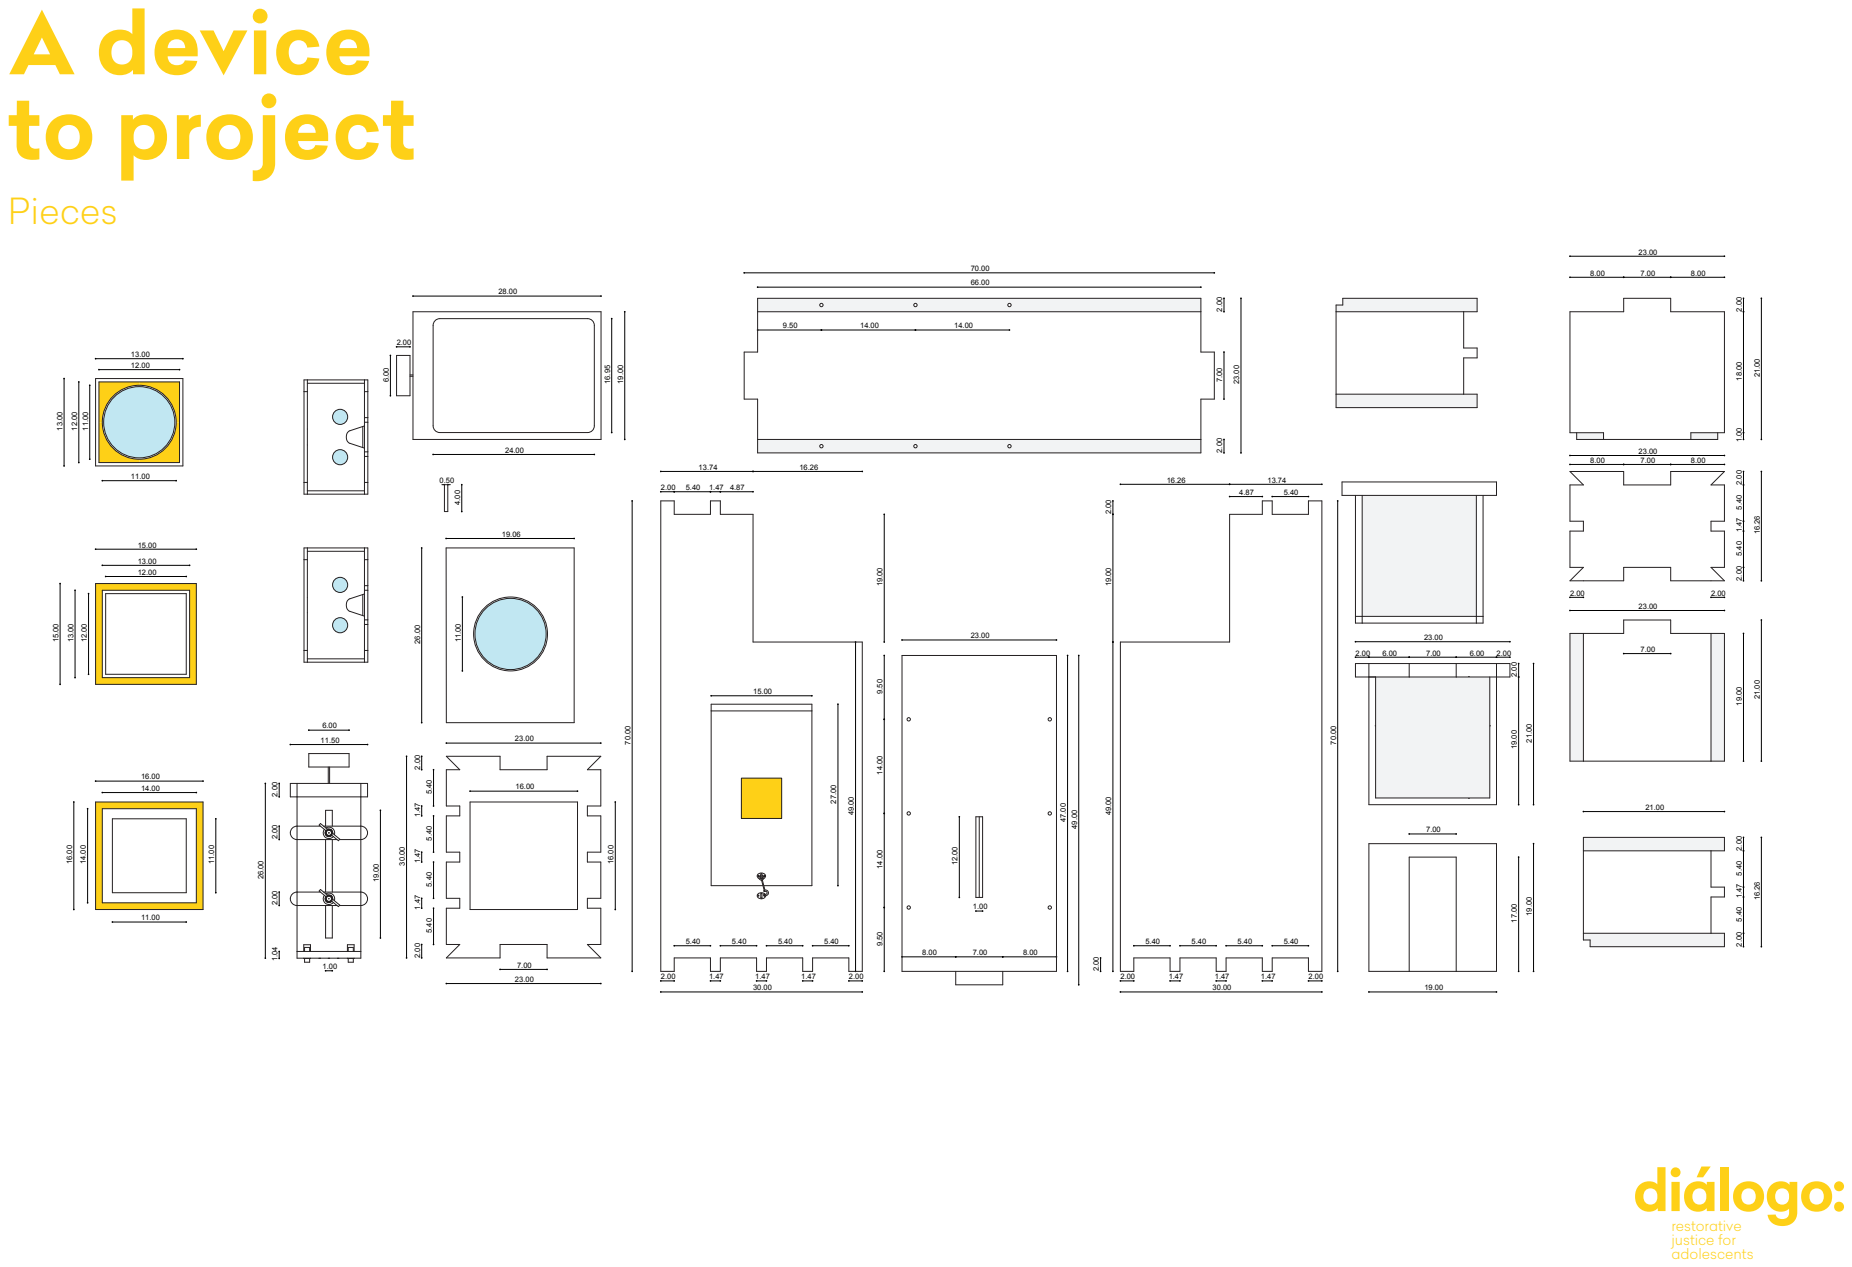
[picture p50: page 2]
diálogo:; to project

# Isometric view of the device

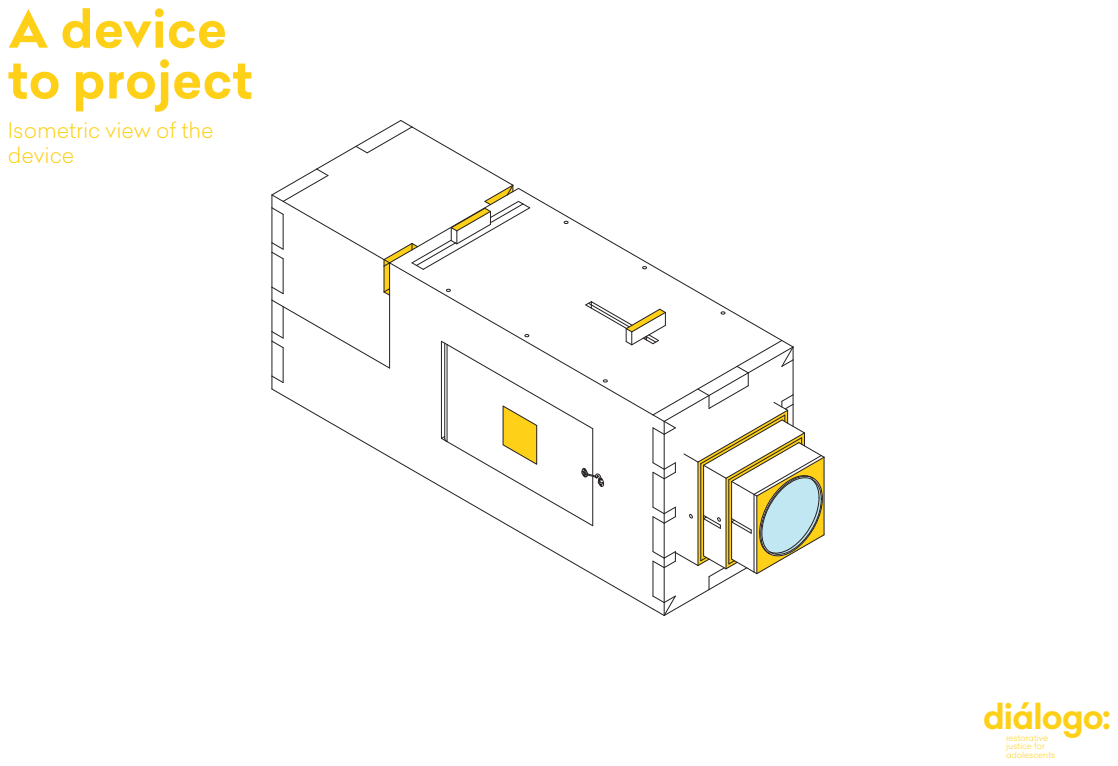
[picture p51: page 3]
diálogo:; A device to project

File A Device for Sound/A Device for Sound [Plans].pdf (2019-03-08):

# Isometric view of the pieces

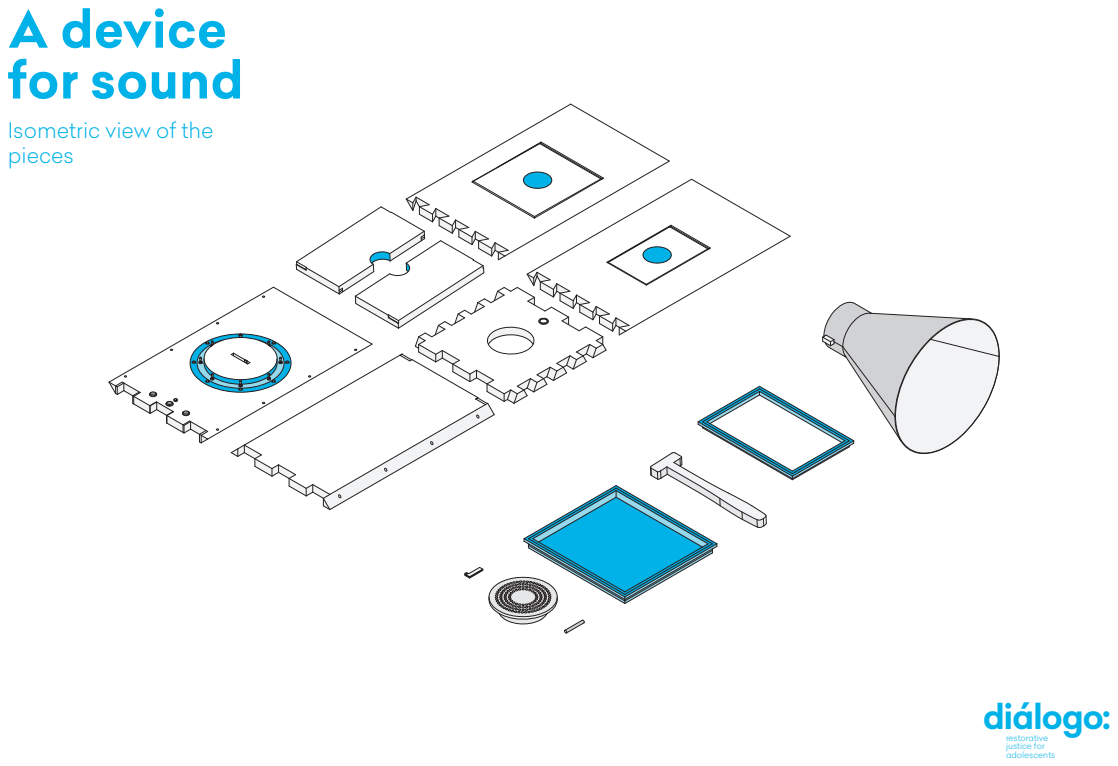
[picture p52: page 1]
restorative justice for adolescents; diálogo:; A device for sound

# Pieces

# A device

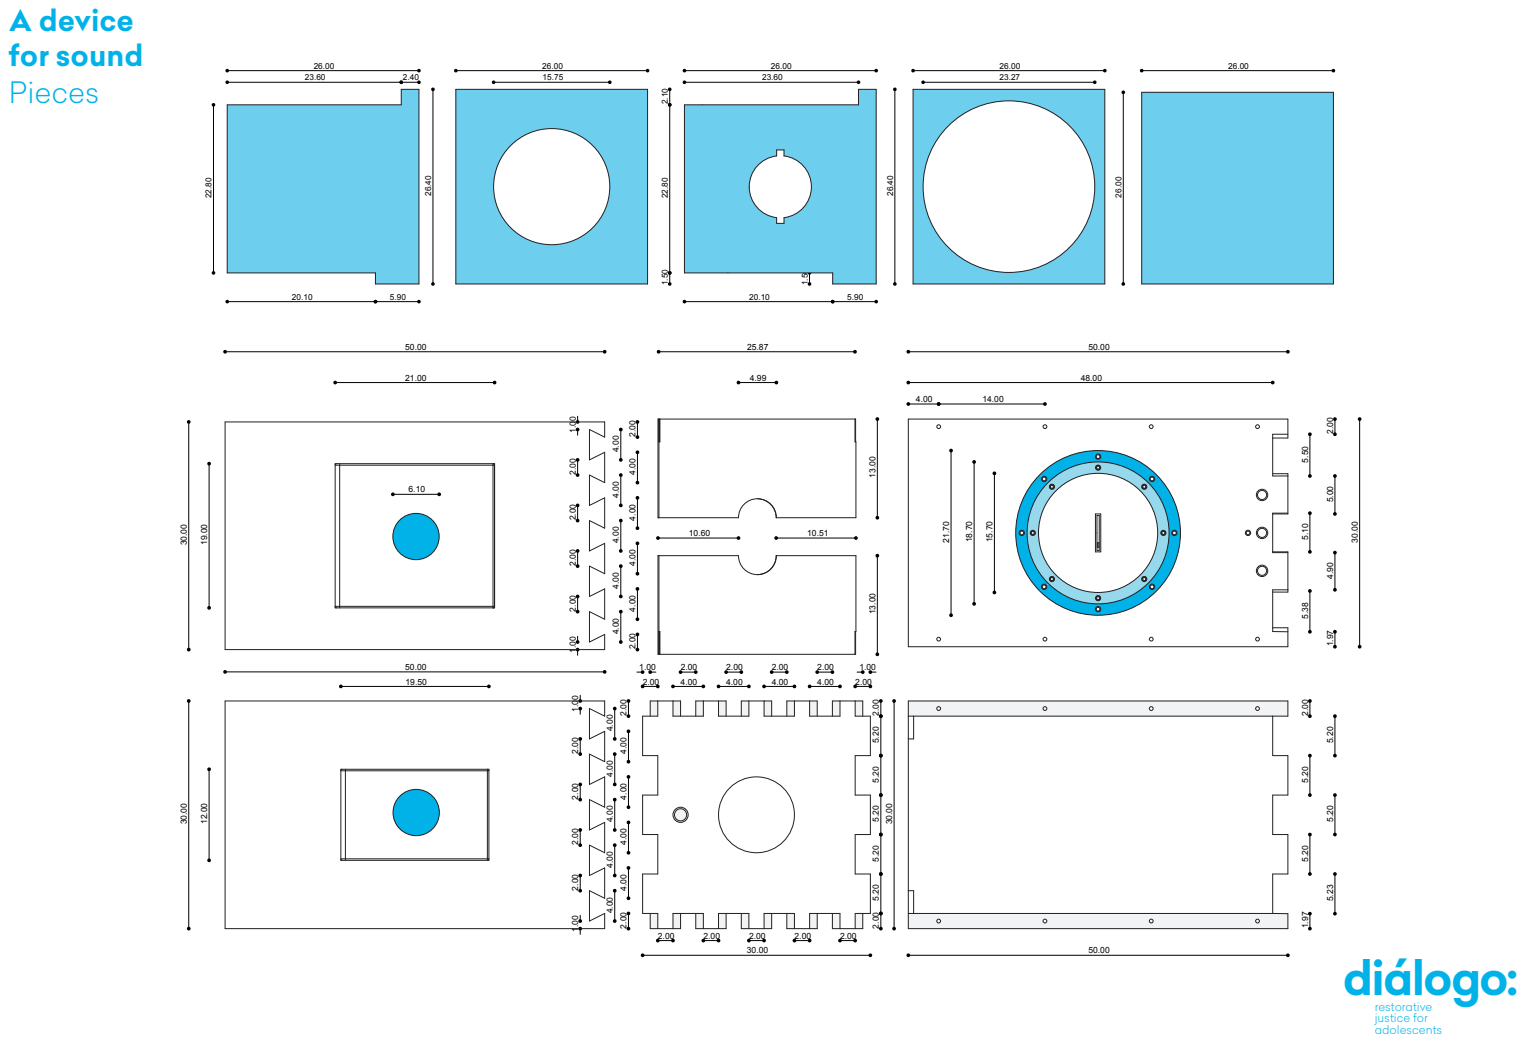
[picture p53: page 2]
diálogo:; for sound

# Isometric view of the device

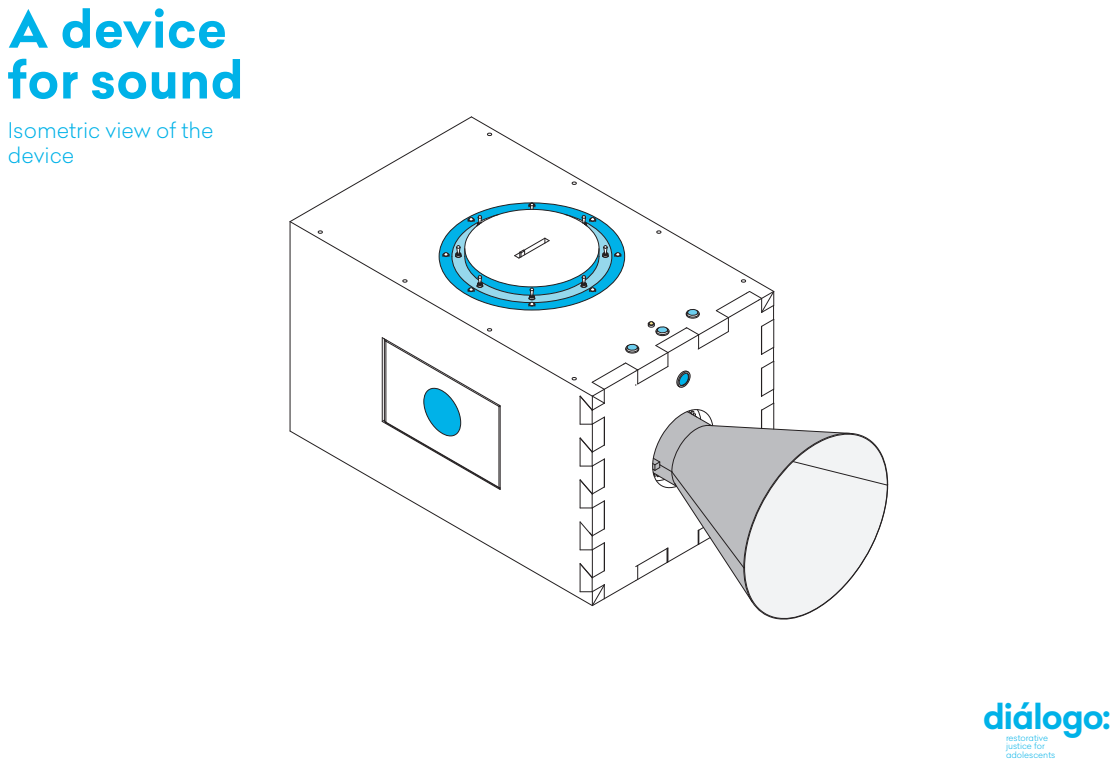
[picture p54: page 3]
diálogo:; A device for sound

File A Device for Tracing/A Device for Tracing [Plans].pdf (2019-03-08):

# Isometric view of the pieces

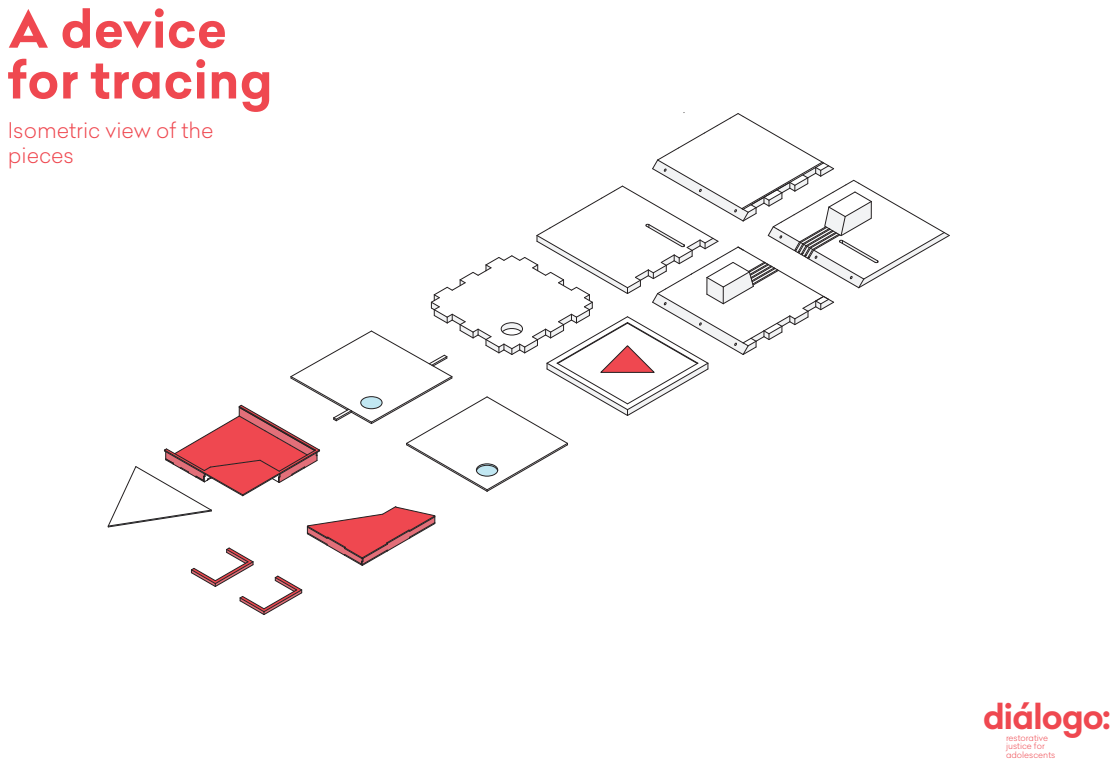
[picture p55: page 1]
restorative justice for adolescents; A device for tracing; diálogo:

# Pieces

# A device

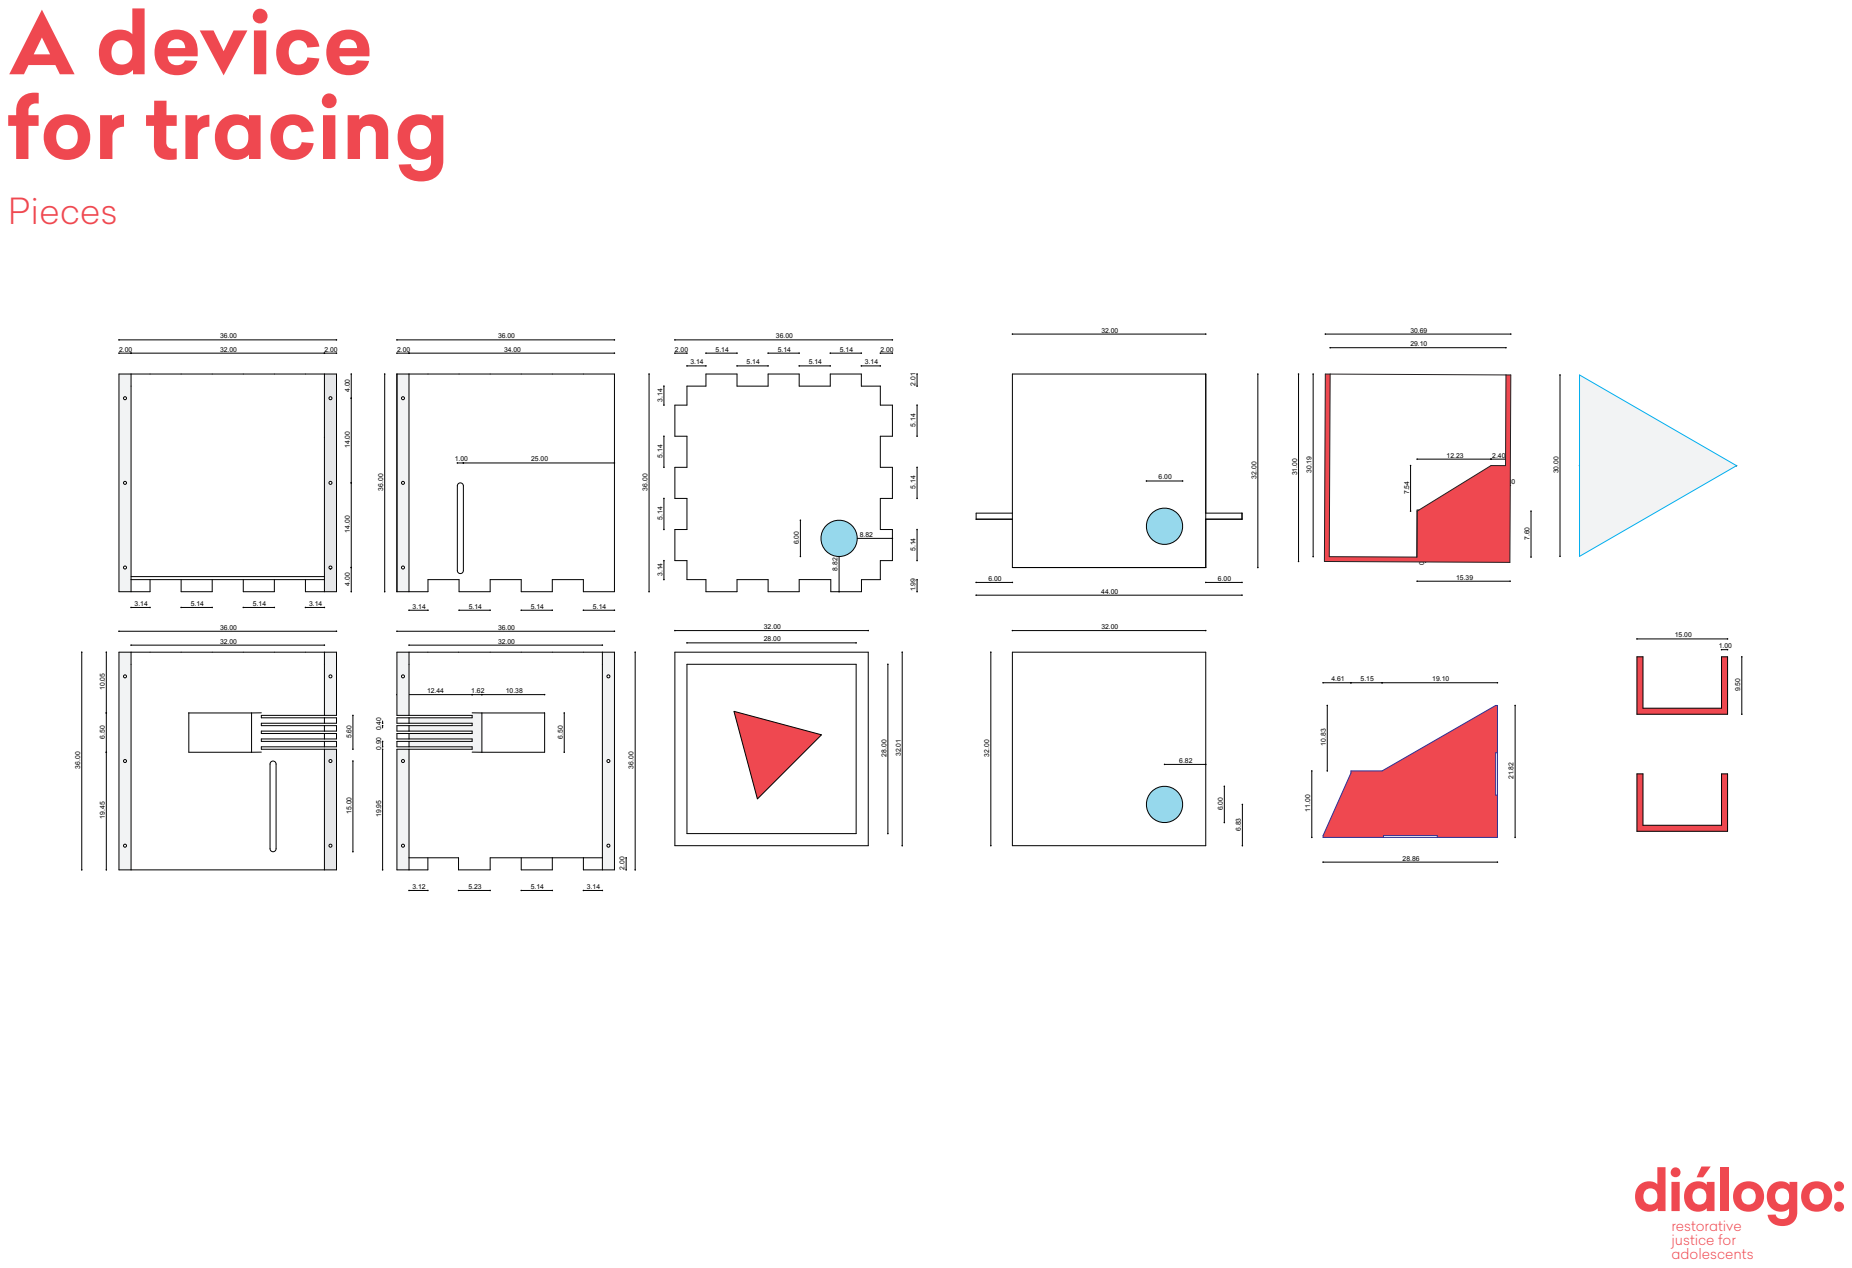
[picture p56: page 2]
diálogo:; for tracing36.00

# Isometric view of the device

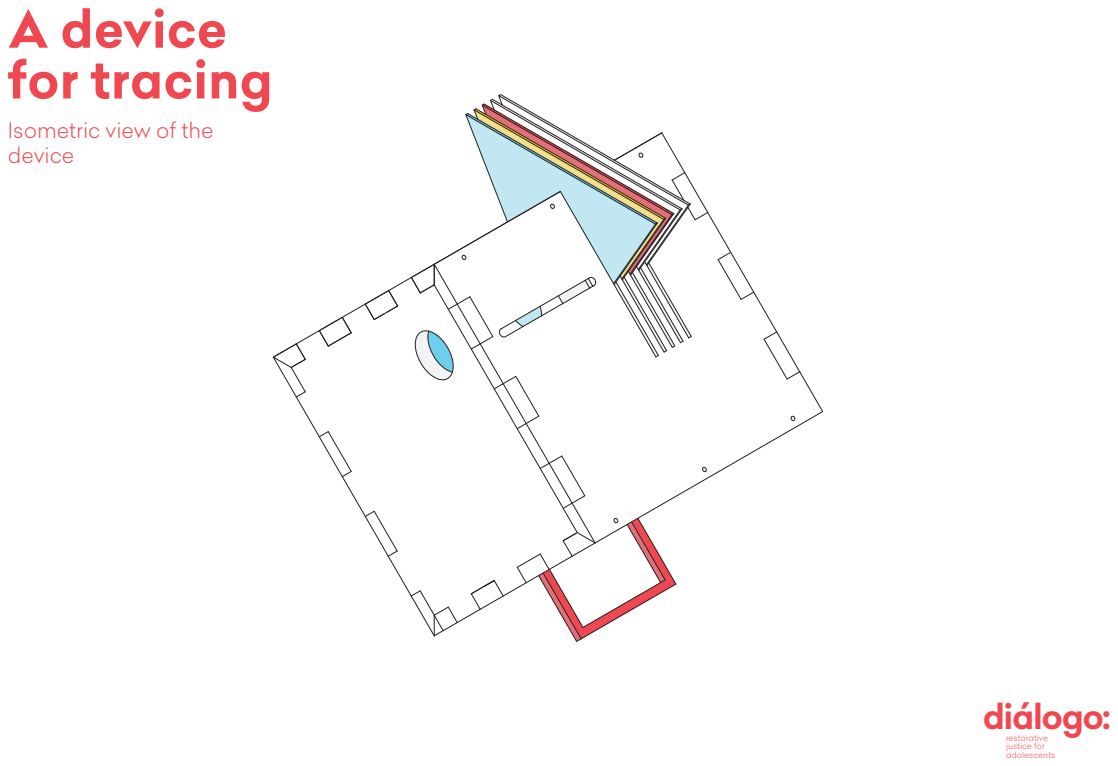
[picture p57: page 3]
diálogo:; A device for tracing
